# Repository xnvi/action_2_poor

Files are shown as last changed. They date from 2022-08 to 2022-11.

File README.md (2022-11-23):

# 简介
买不起DJI Action 2的我仿造了一台Action 2 Poor  

硬件原理图  
https://oshwhub.com/code504/action_2_poor_v1  

软件源码  
https://gitee.com/dma/action_2_poor  

视频演示  
https://www.bilibili.com/video/BV1ND4y1s7Hr  

# 写在前面
* 想买个便宜运动相机的、零基础的、纯外行之类的人不要看了，直接去买便宜的二手运动相机。
* 想要复刻的一定要考虑清楚，千万不要把它真的当成相机来用，视频中也展示过它的画质，这里我再次强调：它的画质很差！
* 本项目的学习意义大于使用意义，如果你以前没有做过这样的项目并能完整复刻下来，或者能在此基础上做二次开发，那么我相信你一定有巨大收获！

# 目录说明
* doc 为项目文档、图片、部分芯片的数据手册等。
* firmware 为编译好的固件，直接烧录就可以运行，例如uboot、kernel、rootfs等。
* hardware 为硬件相关内容，包括原理图、PCB、外壳模型等。
* software 为软件源码。其中 app 内为各个可独立运行的程序，包括 hello world、camera、功能测试程序等；ext_lib 为第三方库如 lvgl、libmpeg等；hisi_sdk 为海思官方sdk文件；patches 为我修改的u-boot和kernel代码；utils 内为本工程的一些未分类的通用代码。

PCB和原理图仅供参考，后续变更以 https://oshwhub.com/code504/action_2_poor_v1 为准，本工程内的PCB和原理图不再更新。  

# 固件说明
firmware 的目录结构及各个文件说明如下  
```
firmware/
├── camera_img                              # 存放我编译的各类镜像，烧到Flash中就能用
│   ├── rootfs.jffs2                        # 我编译的 rootfs
│   ├── uboot_env.bin                       # u-boot环境变量
│   ├── u-boot-hi3516ev200.bin              # 我编译的 u-boot
│   ├── uImage                              # 我编译的 kernel
│   └── update_pack.tar                     # 升级包示例
├── font                                    # 存放字体文件，大家可以自行修改
│   ├── HarmonyOS_Sans_SC_Regular_L1.ttf    # 中文字体
│   └── Inconsolata-Bold.ttf                # 英文字体
└── hisi_official_img                       # 存放由海思官方代码编译的未做任何修改的镜像，供大家开发测试
    ├── rootfs_hi3516ev200_64k.jffs2        # 由海思官方代码编译的 rootfs
    ├── u-boot-hi3516ev200.bin              # 由海思官方代码编译的 u-boot
    └── uImage_hi3516ev200                  # 由海思官方代码编译的 kernel
```

烧写地址  
| 文件名 | 地址 |
| --- | --- |
| u-boot | 0x00000000 |
| u-boot_env | 0x00080000 |
| kernel | 0x00100000 |
| rootfs | 0x00500000 |

* 理论上由海思官方代码编译的镜像可以直接跑起来，容量为8MB或16MB常见品牌的Flash都是支持的
* 保守起见，我的镜像修改了u-boot和kernel的Flash驱动，至少可以保证使用W25Q128JVSIQ能正常启动
* 烧写方法灵活多样，flash内有uboot的可以直接用uboot命令烧写，没有uboot的flash（如不小心全片擦除、全新flash、flash内数据损坏等）可以用hisi sdk内的烧写工具或拆下flash用烧写器进行烧写。无论哪种方式只要能烧进去就行，具体操作步骤请自行百度或查阅hisi sdk内相关文档，这里不再赘述。

# 快速入门

## 零代码开发
针对不想写代码或不会写代码的人，这种方式风险极高，遇到问题很难定位。  

### 准备工作
1. 有焊接能力
2. 有flash烧写工具
3. 除被动型元件（电容、电阻等）以外的所有器件型号必须完全一致
4. 特别说明：目前提供的固件触摸屏坐标范围是0到128，坐标原点在右下角，如果你的触摸屏不符合这个参数就必须修改源码

### 开发过程
1. 焊接并组装
2. 按【固件说明】章节的内容烧写camera_img目录下对应的固件，烧写完成后最好校验一遍
3. 上电，如果运气好，2秒钟左右你会看到Logo，15秒左右会黑屏，紧接着白屏，22秒左右开机完成
4. 如果没有开机、开机白屏、开机后卡死等，检查芯片是否焊接良好，如果确认焊接无误，大概率是芯片挂了
5. 如需帮助请留下详细的故障描述以及完整的串口打印日志（波特率115200），特别是串口日志，非常重要！

## 二次开发
我默认你具备足够的软硬件开发经验，能独立解决开发中遇到的各种软硬件问题，一些基础性的东西例如设置uboot环境变量、编写CMake脚本、git常用命令、Linux常用命令等我默认你都会。  

### 准备工作
1. 有足够的C语言开发经验，具备一定Linux基础，有焊接能力
2. 准备海思官方SDK，版本为 Hi3516EV200R001C01SPC012 （这东西是保密的，我不想给自己找麻烦，别找我、我没有、不知道，否认三连。【疯狂暗示：用各种搜索引擎搜索“Hi3516EV200R001C01SPC012”、“海思SDK”、“Hi3516EV200 SDK”等关键字，这里的各种搜索引擎包括但不限于百度、Bing、Google、网盘搜索、磁力搜索、各种论坛的内部搜索、某些购物软件的搜索栏、公众号等】）
3. 按照海思SDK中的说明安装交叉编译工具链 arm-himix100-linux
4. 如果你想要自己编译uboot、kernal、rootfs，请按照海思SDK中的相关文档搭建开发环境；如果不想编译上述内容，可以跳过这个步骤，直接用我提供的
5. 拷贝海思官方SDK内的相关文件，本工程用到以下文件：
	hisi_sdk 内用于存放海思官方sdk文件
	请自行拷贝以下文件到 `hisi_sdk\` 目录内
	Hi3516EV200R001C01SPC012.rar -> Hi3516EV200R001C01SPC012\01.software\board\Hi3516EV200_SDK_V1.0.1.2.tgz -> Hi3516EV200_SDK_V1.0.1.2\package\mpp.tgz -> mpp\
	这个目录下的 include, ko, lib 三个目录

### 编译说明
在 `software/CMakeLists.txt` 中设置海思交叉编译工具链路径  
编译命令  
```
cd ./software
mkdir ./build
cd ./build
cmake ../
make
```

### 运行程序
**有嵌入式linux开发经验的可以自行操作，本章节内容仅供参考**  

烧写完成后需设置uboot环境变量，输入以下命令设置环境变量，保存并重启，正常情况都会成功。  

我编译的镜像使用以下环境变量  
```
setenv bootargs 'mem=36M console=ttyAMA0,115200 clk_ignore_unused rw root=/dev/mtdblock2 rootfstype=jffs2 mtdparts=hi_sfc:1M(u-boot.bin),4M(kernel),11M(rootfs.jffs2)'
setenv bootcmd 'startrgb; sf probe 0; sf read 42000000 100000 400000; bootm 42000000'
setenv bootdelay '1'
saveenv
reset
```
为了加快开机速度可以把 bootdelay 改成 1，但不建议改成 0，你清楚这意味着什么吧？  

海思官方镜像使用以下环境变量  
```
setenv bootargs 'mem=32M console=ttyAMA0,115200 clk_ignore_unused rw root=/dev/mtdblock2 rootfstype=jffs2 mtdparts=hi_sfc:1M(u-boot.bin),4M(kernel),11M(rootfs.jffs2)'
setenv bootcmd 'sf probe 0; sf read 42000000 100000 400000; bootm 42000000'
saveenv
reset
```

**以挂载nfs并运行程序为例**  
linux内核启动后输入以下命令启动网卡、设置IP、网关等  
```
ifconfig lo 127.0.0.1
ifconfig eth0 192.168.1.2 netmask 255.255.255.0
route add default gw 192.168.1.1
```

在虚拟机中安装nfs server，设置有线网卡的ip为`192.168.1.3`，在开发板上挂载nfs（土豪可以用NAS之类的，普通人用linux虚拟机）  
```
mount -t nfs -o nolock 192.168.1.3:/home/nfs /tmp/nfs
```

在nfs server的目录内准备上文提到的ko、lib目录，以及要运行的程序，输入以下命令加载ko  
```
cd /tmp/nfs/ko
./load3516ev200 -i -sensor0 imx335
```
load3516ev200 脚本中的内存可以自行修改，但必须和bootargs的mem保持一致  

输入以下命令设置环境变量  
```
export LD_LIBRARY_PATH=$LD_LIBRARY_PATH:/tmp/nfs/lib
```

运行你的程序  

# 硬件开发

## 硬件成本与采购渠道
如果你打算自己手工焊接，并且使用3D打印外壳，成本最低可以控制在300元以内，但如果你打算正反面全贴片并且使用CNC外壳，那么会直接飙升到一千元，总之就看你的钱包能不能承受得住。  
为避免不必要的麻烦，详细内容以及采购渠道请查看 doc 目录中的《成本估算及采购渠道.xlsx》  

## 打样参数
| 名称 | 层数 | 厚度 | 备注 |
| --- | ---- | --- | --- |
| 串口网口转接板 | 2 | 无要求，1.6mm即可 | 无 |
| 屏幕转接板 | 2 | 尽量薄，建议0.8mm | 无 |
| 副板 | 2 | 建议0.8mm | 有能力的最好做阻抗匹配 |
| 主板 | 4 | 建议1.0mm | 有能力的最好做阻抗匹配 |

## 串口与网口转接板
4块PCB中最简单的一块，就是把串口和网口引出来而已，方便调试。串口的作用还用说？网口主要是挂载NFS进行开发调试，不用网口也行，无非就是用SD卡烧写程序测试，但这样做效率太低，而且不能用GDB Server进行调试。  
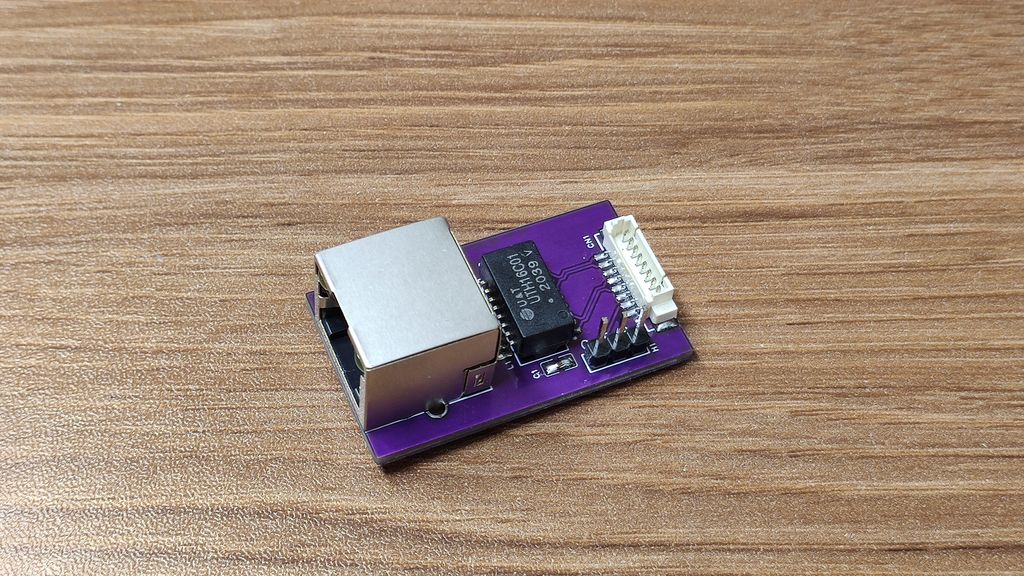
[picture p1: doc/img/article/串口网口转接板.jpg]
  

## 显示屏与触摸屏转接板
显示屏与触摸屏通过一块转接小板与主板连接，这样设计有两个原因：  
1. 主板没有多余的面积放置显示屏与触摸屏的接插件
2. 当后期需要更换线其他型号显示屏或触摸屏时，只需重新画转接小板即可

转接板尽量薄一些，这样可以尽可能多得节省内部空间来放置更大容量的电池。这里转接板的厚度为0.8mm，是嘉立创能免费打样的最小厚度。  

**规格型号**  
触摸屏：1.54寸，主控FT6206，6PIN，IIC接口  
显示屏：1.33寸，主控ST7789，12PIN，SPI接口  

**注意事项**  
1. 市面上有很多儿童手表或智能手表的屏幕总成，理论上买这种屏幕是最好的，但我找了多家店铺屏并没有找到合适的屏幕，主要有以下几个原因：没有合适的尺寸；采用BTB接口的屏幕较多，母座难以手工焊接；最重要的一点，没有引脚定义，更不知道触摸屏和显示屏芯片的型号，大多店家只是代理商，他们只负责销售，不是他们不提供资料，是他们也没有资料。如果大家能找到合适的且有完整资料的手表屏幕总成，欢迎分享。（当我整理文档时网上已经可以买到一款1.69寸240x280的屏幕总成了，很多开源项目也在用这款屏幕，但很可惜长度长了一些，不然我就换用这款屏幕了）
2. 显示屏优先选择1.33寸的（有的可能叫1.3寸），不推荐1.44寸和1.54寸。1.44寸的屏幕尺寸比较合适，但分辨率只有128x128，如果你一定要用这款屏幕，那么所有和显示先关的代码都要改，工作量可不小。1.54寸的屏幕显示区域和触屏区域完美重合，但很可惜显示屏的四个角会超出触摸屏一点点，如果显示屏边框是塑料，可以尝试用刀割一点点，如果显示屏是金属外壳就不太好办了。其次是留给触摸屏四周的边框太窄了，和外壳粘接比较困难，还有就是屏幕排线的位置也不太合适，排线距离边框太近，安装时外壳可能会过渡弯折排线导致屏幕损坏。所以我这里只能选用1.33寸的屏幕，这个显示屏和触摸屏之间有大约1.5mm的白边，不易处理，而且显示面积小，确实有点费眼睛。这两种种屏幕对比如下：
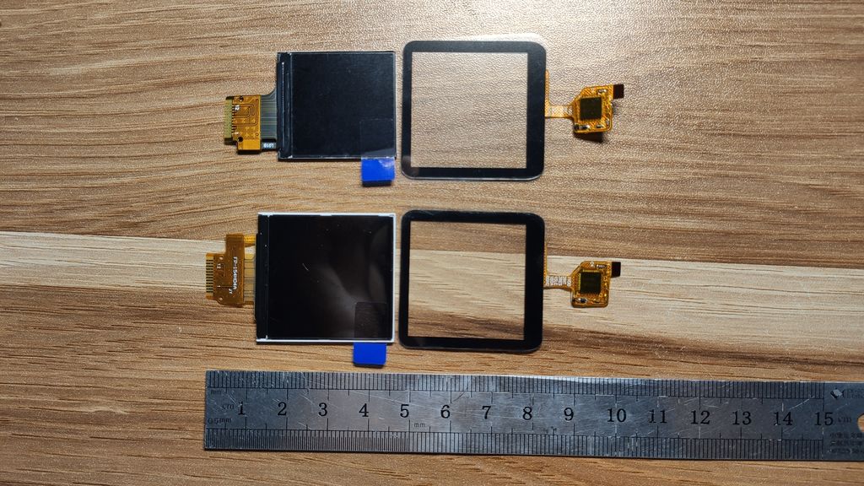
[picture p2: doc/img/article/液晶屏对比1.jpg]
     
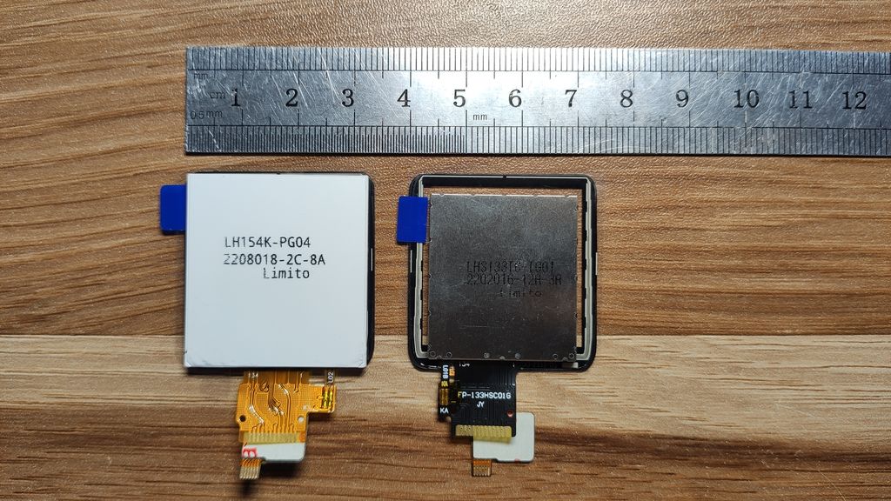
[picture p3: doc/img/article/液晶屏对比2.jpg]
     
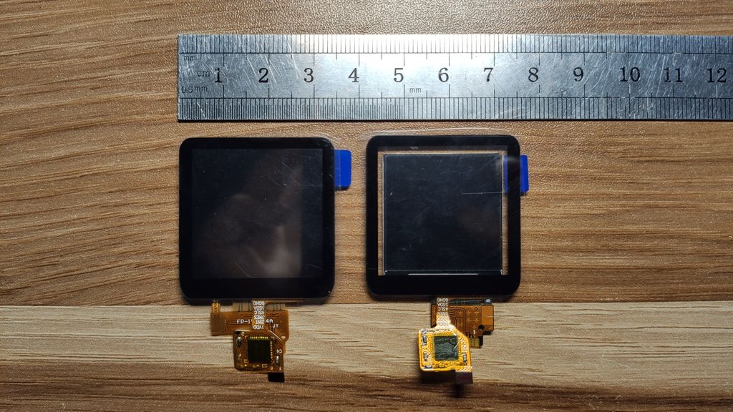
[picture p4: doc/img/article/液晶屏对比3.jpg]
     
3. 如果换了不同尺寸的显示屏，最好在代码中校准一下触摸屏和显示屏的坐标，比如我用的1.33寸显示屏比触摸范围小一圈，触摸的横纵坐标应该都减去一定值，具体内容看源码
4. 最开始我打算用黑色的T7000手机屏幕维修专用胶水来粘接显示屏与触摸屏，正好黑色也可以遮挡白边，计划是将胶水涂在显示屏与触摸屏接触面的拐角处，并用胶水覆盖白边，这样粘接的好处是一旦发现触摸屏或显示屏有损坏等情况，除胶拆卸也比较方便。真正粘接前还专门在钢化玻璃贴膜和亚克力上试了试，发现胶水的流动性不强，我以为没问题，实际粘接时发现胶水会渗入屏幕之间，幸亏拆的快，不然这两块屏幕就有可能报废了。所以我最后用3mm宽的黑色的手机维修泡棉双面胶来粘的屏幕，这三边用黑色泡棉胶带呈L形粘贴屏幕边框和触摸屏。
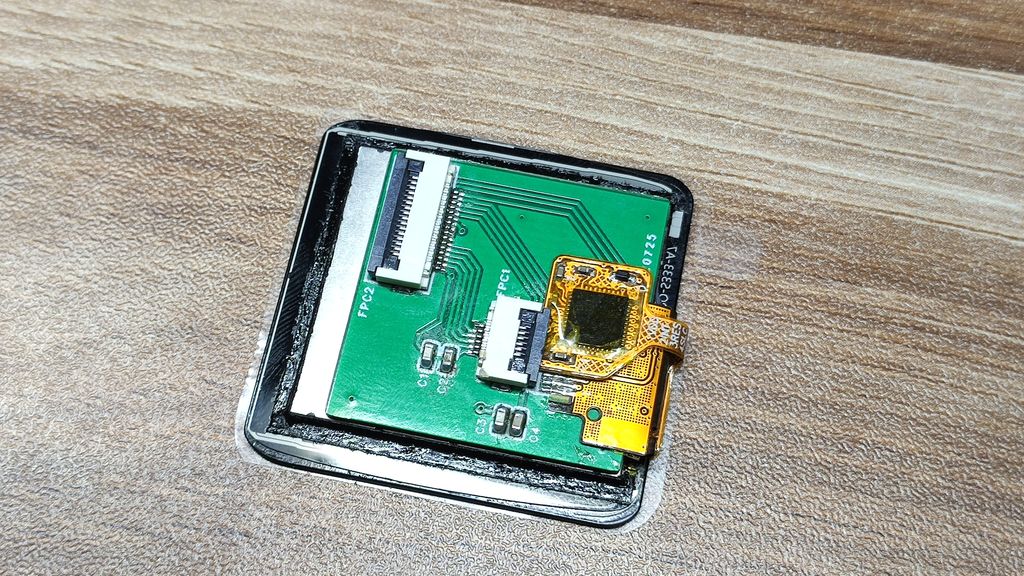
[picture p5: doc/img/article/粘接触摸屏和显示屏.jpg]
     
5. 如果不打算维修，或不考虑以后进行无损拆解等，可以考虑OCA光学胶，这也是理论上最理想的选择，因为现在几乎所有的手机屏幕都是用这种胶粘的，但实际情况是没有专业工具粘接必然有气泡残留，这胶的粘性还挺强，后期维修拆解困难，残留难以清除（看维修手机的视频就知道这胶有多难处理），所以也不推荐。如果你是个修手机的，手头正好有压屏机，那当我没说。我用两张报废的手机膜做测试，粘接后有气泡残留。
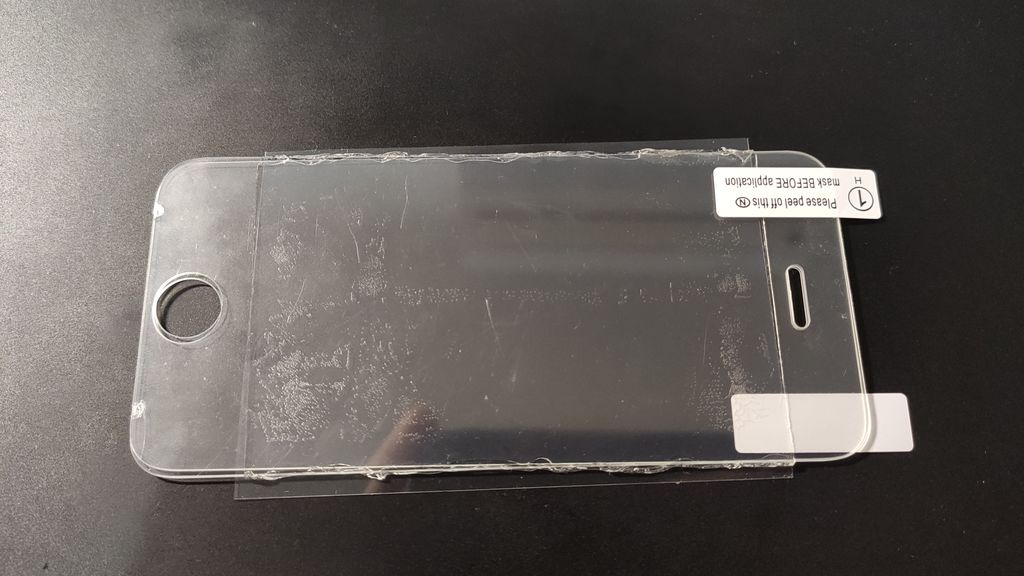
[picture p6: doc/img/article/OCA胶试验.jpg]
     
6. 触摸屏的FPC排线很短，FPC座这里的小突起会压到触摸屏排线，需要把这里剪掉，推荐用指甲刀
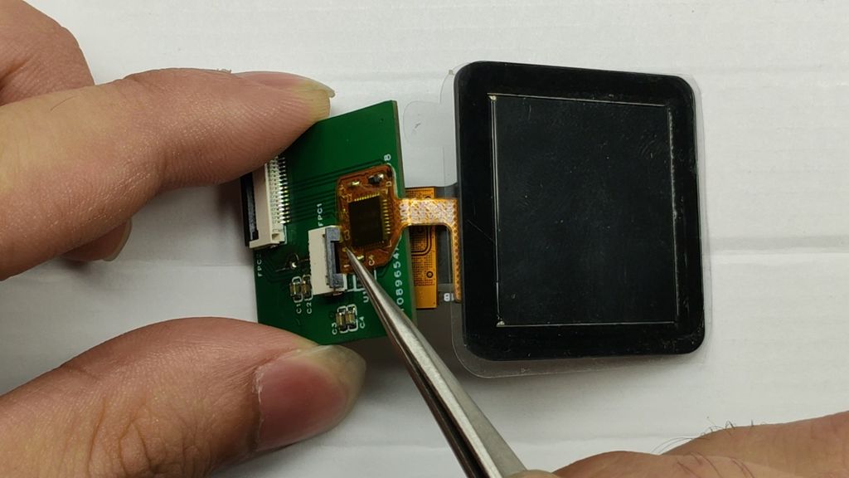
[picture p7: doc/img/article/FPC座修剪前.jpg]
     
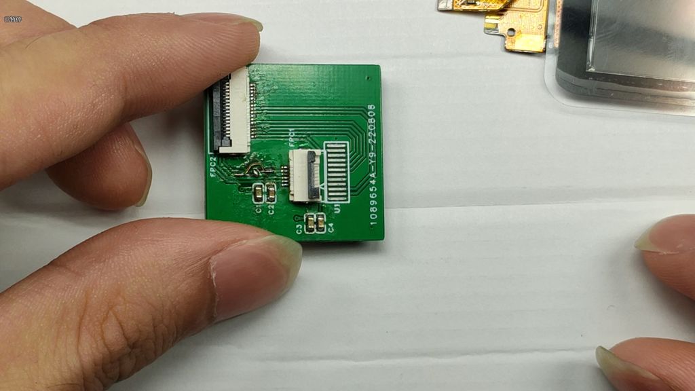
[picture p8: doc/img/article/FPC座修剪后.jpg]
     
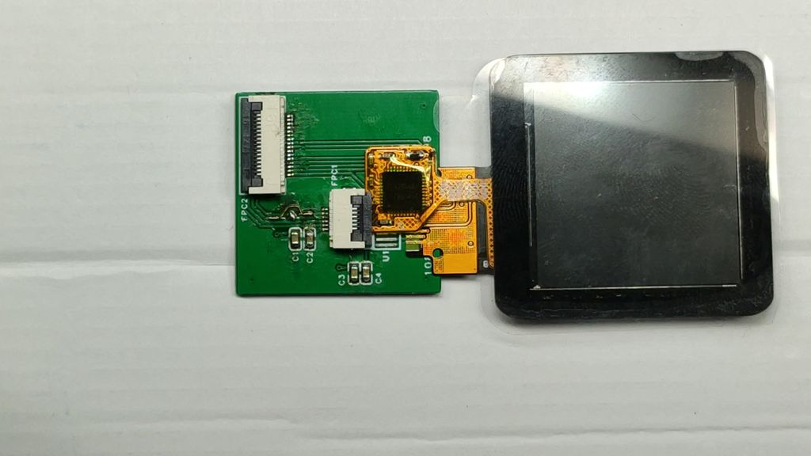
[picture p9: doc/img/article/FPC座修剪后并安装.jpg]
     

## 副板
1. 目前没有做回放功能，也没有提示音之类的，可以不焊接功放芯片。
2. type-c有两对信号线，我的PCB中只连接了一对，不影响使用，何况我也没开发USB功能，如有需要请自行修改。
3. USB信号线没做阻抗匹配，如有需要请自行修改。
4. 充电芯片是TP4057，目前设置的充电电流大约为0.36A，且电源输入端加了分压电阻，芯片几乎不发热。如需调整充电电流请注意散热问题。

## 主板
1. 在主板的Flash旁边预留了5V和GND焊盘，开发期间可以用这个焊盘供电，省去电池。也可以给副板的电池引线接上可调电源。
2. 主板左下角和右下角螺丝孔旁边故意没有铺铜，外壳（尤其是CNC外壳）这里如果有弧度正好可以手动把这里磨成圆的。为什么不在PCB里面就做成圆的？因为懒。
3. 主板上其他设计细节请查看原理图中的注释
4. MIPI、ETH、USB信号线需要做阻抗匹配，但是我没做，能用就行。（其实是我不会）
5. 主控我买的二手拆机摄像头，这种价格便宜但不包好坏，有的板子有明显的暴力拆解痕迹，这种芯片完全看运气。

谁呀这么倒霉？怎么这么多芯片都坏了？哎？你们别看我，这个倒霉蛋绝对不是我！我不知道，我没有狡辩，真的不是我！  
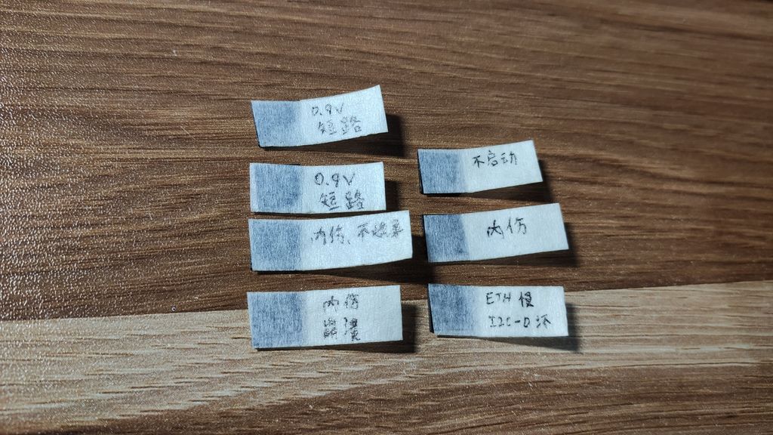
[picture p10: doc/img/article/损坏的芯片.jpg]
  

## FPC排线处理
* FPC排线的长度建议为3CM
* 为了节约PCB面积整个电路设计很紧凑，所有FPC连接器的位置都很靠边，而FPC加强筋又比较长，不方便弯折，所以需要减掉一些加强筋。
* 如果加强筋的金手指比较长，可以直接从加强筋前面减
* 如果加强筋的金手指比较短，需要从后面把加强筋和排线撕开，然后剪短（有的排线质量非常好，加强筋根本撕不开，可以适当加热辅助，如果还撕不开就换个渠道再买一些吧）
* 推荐使用指甲刀剪

剪加强筋之前  
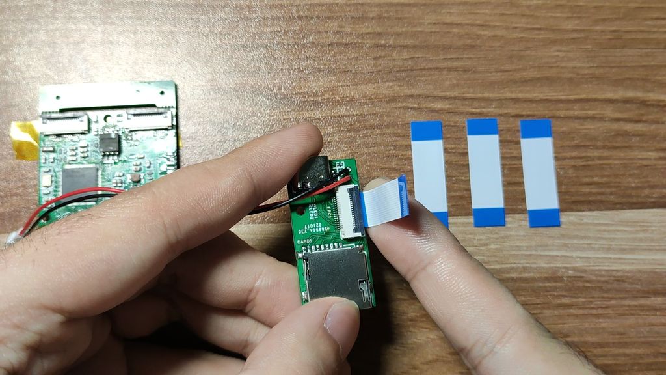
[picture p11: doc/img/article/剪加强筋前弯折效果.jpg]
  
剪加强筋之后  
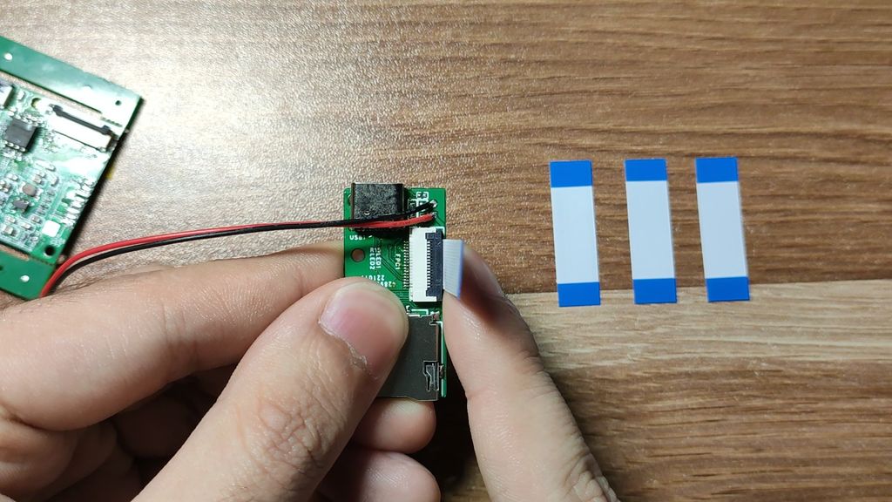
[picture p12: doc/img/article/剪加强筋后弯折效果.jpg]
  
撕加强筋  
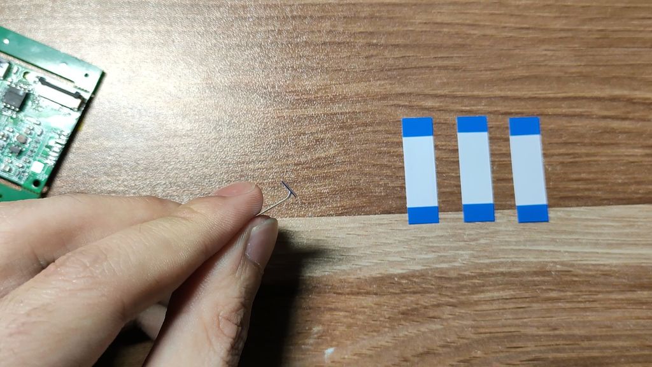
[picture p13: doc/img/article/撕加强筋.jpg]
  

## 摄像头处理
摄像头的排线需要弯折，弯折后效果如下，保证摄像头正好在线框位置上，并使用双面胶粘牢  
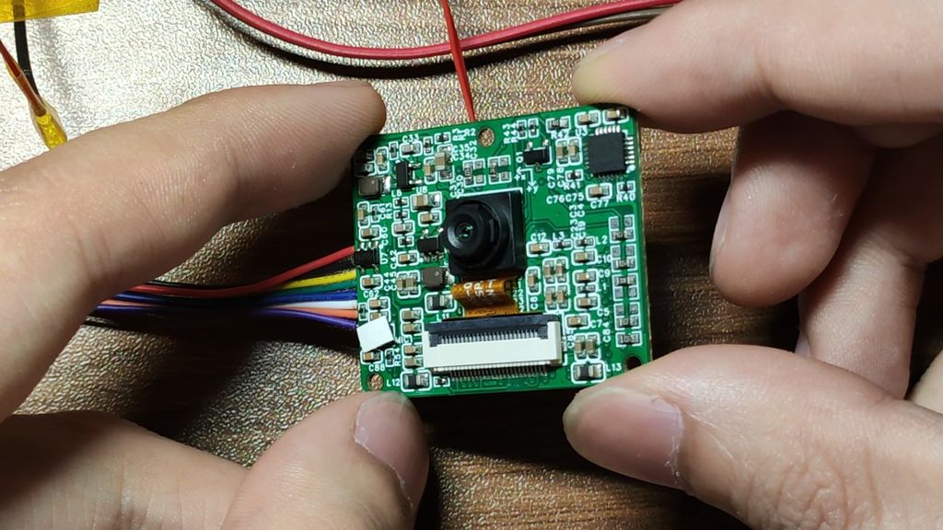
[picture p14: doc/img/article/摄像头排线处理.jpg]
  

## 主控芯片焊接注意事项
1. 一定要检查，有维修专用显微镜之类的最好，如果没有，最起码也要买个10倍的放大镜，引脚非常小，没有放大镜的话你的眼睛受不了。
2. 有钢网可以直接用热风“木仓”一次性焊好，没有钢网先用热风“木仓”把底部焊盘焊好，再用烙铁焊接引脚（焊接老手直接用热风“木仓”搞定，根本不用烙铁补焊）。
3. 焊接引脚没什么技巧，多多练习，熟练了就好，如果你能顺利手工焊接ESP32，那么焊接这个芯片相对来说也没那么困难。

以下是个人总结的手工焊接建议，仅供参加考  
* 这个芯片的主要来源是拆机芯片，焊接前仔细清理引脚（如果能买到全新，忽略此条）
* 手工烙铁焊接不建议用锡膏，因为在芯片的边角处很容易残留未熔化的锡膏，可能埋下隐患，这些未熔化的锡膏用放大镜仔细检查就能发现，但肉眼基本看不见
* 烙铁头个人觉得用小刀头最合适，其次是小一字头，再其次是特尖头，马蹄头不考虑
* 助焊剂优先推荐BGA专用助焊剂，再其次是一些维修专用助焊剂；不推荐松香（残留多，不方便后期检查），千万不要用一些弱酸性或可能具有轻微导电性的助焊剂，这种助焊剂如果洗不干净隐患无穷
* 少加一点点助焊剂，一点点就行，烙铁头带适量焊锡，从左到右慢慢拖焊，经验丰富的老手用适量的助焊剂和焊锡拖焊一遍就能成功
* 焊接完成后一定要用放大镜仔细检查

这是购买的二手电路板没有拆下芯片之前的样子，焊接效果良好、锡球饱满  
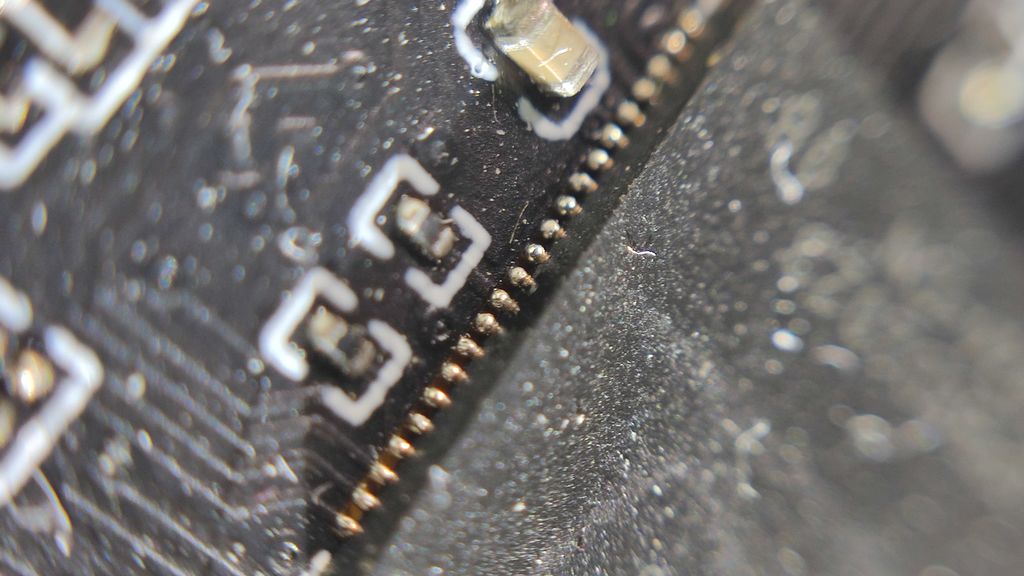
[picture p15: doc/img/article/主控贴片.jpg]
  
正常焊接后的效果如下，可以看到QFN侧面引脚都有锡  
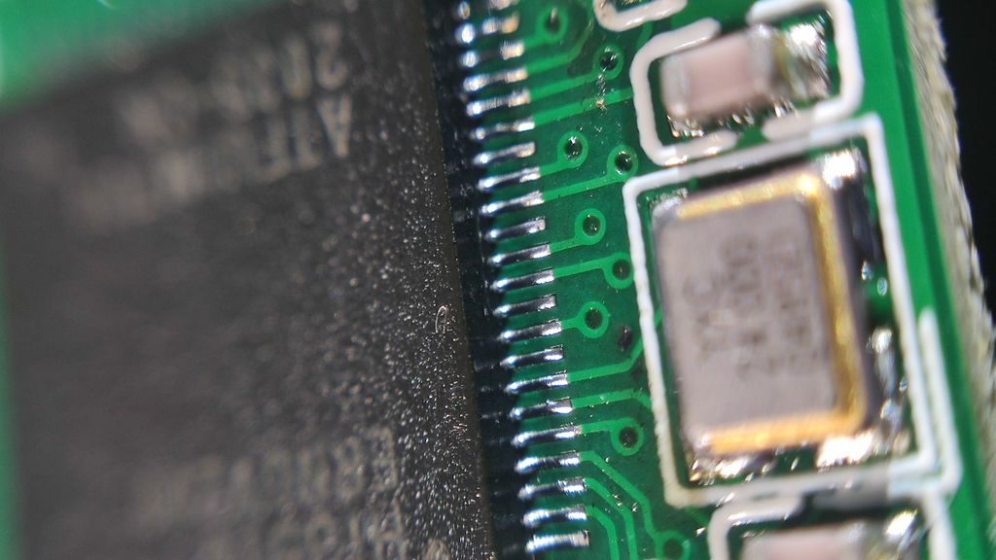
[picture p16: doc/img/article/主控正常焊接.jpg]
  
虚焊的效果如下，QFN侧面引脚没有锡  
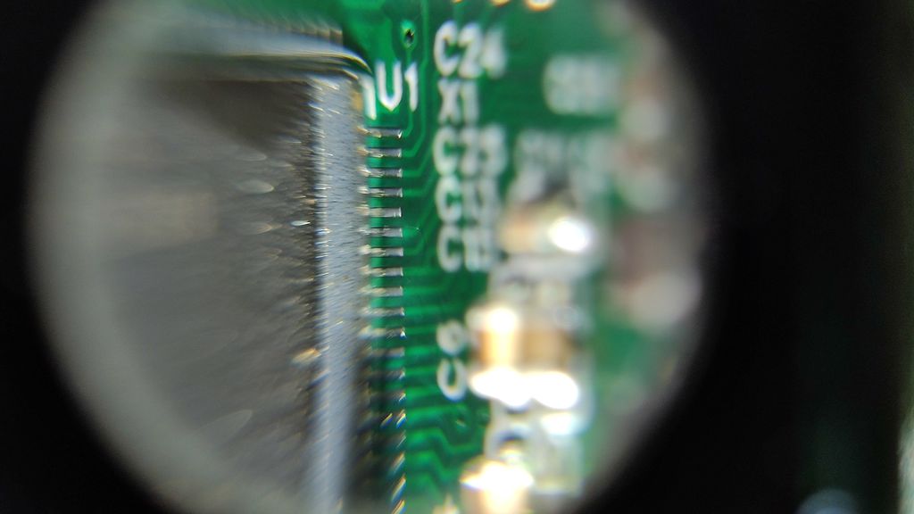
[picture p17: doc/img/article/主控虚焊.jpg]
  

## 其他芯片焊接注意事项
* 当前使用的这颗硅麦需使用热风“木仓”焊接
* 焊接硅麦时特别要小心，任何助焊剂等物质不得进入麦克风的收音孔内（这是麦克风的手册中特别强调的内容）
* 洗板时也要注意，任何洗板水等物质不得进入麦克风的收音孔内（这也是麦克风的手册中特别强调的内容）

# 结构开发

## 3D打印外壳
* 首先排除树脂（如果是自己打印排除PLA），原因是不耐高温，三维猴提供的几种树脂材料的热变形温度差不多在60度左右（PLA的热变形温度也差不多是60度左右），相机工作时发热量巨大，会导致外壳变形。
* 优先选择尼龙，它的热变形温度接近100度左右，价格也不贵。
* 不差钱可以考虑工程塑料，也耐高温，价格比尼龙略贵。
* 至于不锈钢3D打印，价格几乎和CNC差不多，有土豪朋友可以试试，我的钱包伤不起。

## CNC外壳
* 根据工艺不同价格约220到240左右。
* 目前我采用的工艺为：±0.10mm Ra3.2 喷砂-120目 普通阳极氧化-10-15μ-亮光

## 按键
* 按键采用iphone4、5、6的home键，价格在1到3元左右。
* 不要买6s及之后的按键，它有指纹，且价格更贵。

## 电源开关
想打印的就去打印，不想打印的找一小块塑料，自己用刀子刻一个也行（谁小时候没有刀子刻过铅笔呢？）  

## 镜头膜
* 买随便买一个大疆Action2的镜头钢化玻璃膜就行
* 各家店的镜头膜尺寸不同，以我手头为例，就有29mm和28mm两种，强迫症自己去改模型，不是强迫症就凑合用吧
* 很多人不知道的是钢化膜内层其实还有一层膜，记得把它撕掉，然后再用透明双面胶（例如0.1mm到0.3mm厚PET双面透明胶）或胶水（例如UHU胶）什么的把它粘在外壳上

我手头的两种钢化膜尺寸  
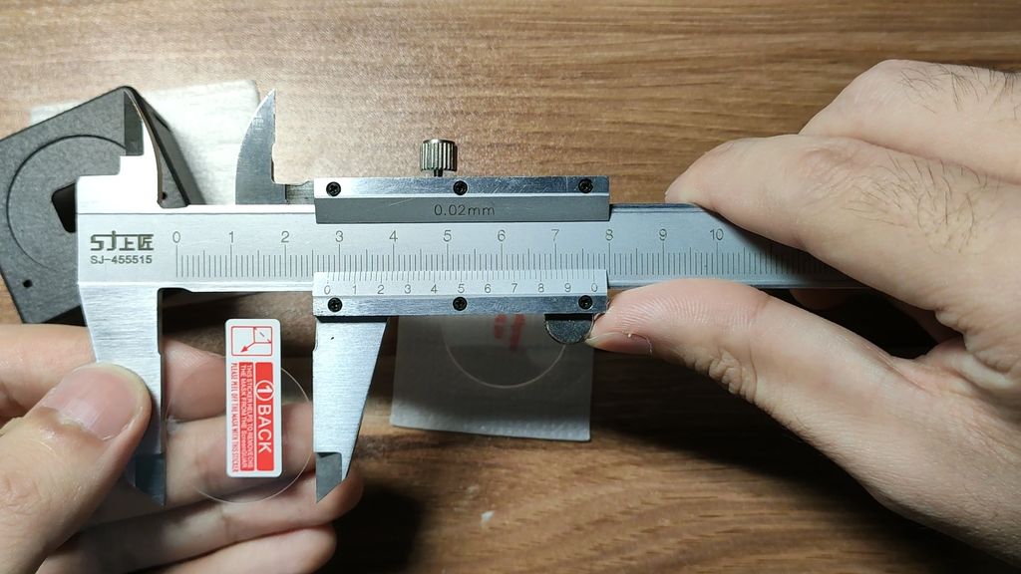
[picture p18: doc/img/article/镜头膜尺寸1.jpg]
  
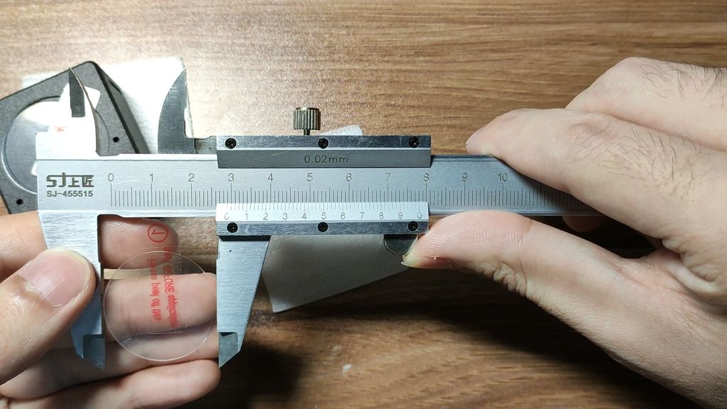
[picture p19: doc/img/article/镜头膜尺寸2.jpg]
  
钢化膜内层的膜用小刀稍微使劲就能划出痕迹  
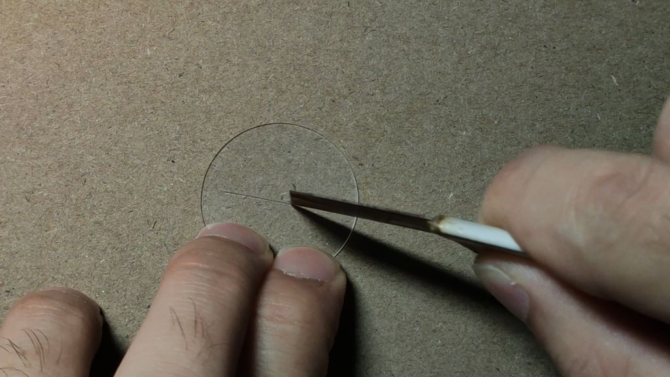
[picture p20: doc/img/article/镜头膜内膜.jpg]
  
再使点劲把膜划烂，撕掉就行，安全第一，注意别伤到手，也别把钢化玻璃弄碎了  
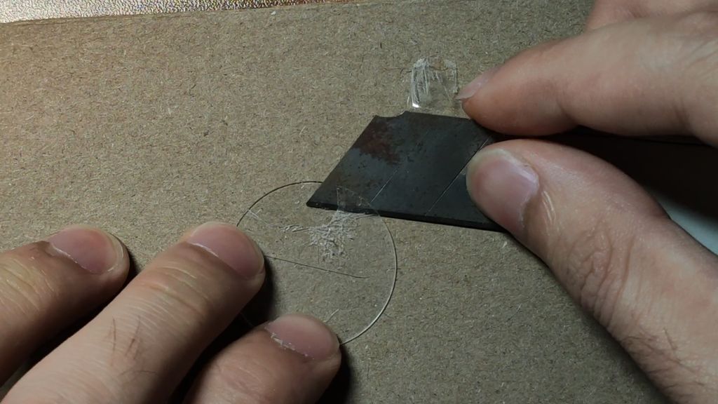
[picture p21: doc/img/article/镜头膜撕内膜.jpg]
  

## 外壳组装说明
先说一个很严重的问题：铝合金外壳会干扰电容屏，从电容屏的原理上讲，这是无法避免的。我尝试了加厚电容屏下胶带厚度，使电容屏尽量远离金属边框，但依然有干扰，所以最后无奈只能使用3D打印的边框，视频中也能看到，成品前面两个外壳用的是铝合金，后面屏幕边框用的是尼龙，外观有点丑。如果有行之有效的改善电容屏干扰的方法，欢迎与大家分享！  

CNC外壳前期准备工作  
* 对于CNC外壳定义装镜头玻璃的为前壳，中间的为侧壳（中壳），装屏幕的为后壳
* 使用透明环氧胶将前壳和侧壳粘在一起，前壳和侧壳要一次性粘接到位
* 粘接时必然会有部分胶水溢出，溢出的胶水需要及时处理，一旦胶水固化就难办了
* 个人经验，环氧胶的初步固化时间约5分钟（具体时长看说明书），涂胶后等个两分钟左右，这时胶水的流动性变差但有没有完全凝固，使用类似牙签之类的有一定硬度且不会划伤外壳的东西尽快把溢出的胶水扣掉
* 等待24小时完全固化后你就得到了一个外壳

CNC外壳相比与3D打印外壳少了一些如螺丝柱之类的结构，这样做的目的是为了降低加工费用，也许我这样设计的CNC外壳不够合理，欢迎提出改进意见。  
其余步骤3D打印外壳的组装步骤和CNC外壳的组装步骤基本一致（定义上一步粘好的CNC外壳为前壳，装屏幕的为后壳）
* 对于CNC外壳，购买若干5mm高的m2螺丝柱，对照PCB的螺丝孔位置，使用环氧胶粘在前壳上，待胶水完全固化后再进行下一步
* 对于CNC外壳，如图所示，找一些小塑料块之类的东西粘在距离前边框3mm处，塑料块不要太高，以免碰到副板上的元件，这里的塑料块可以粘死（这一结构是为了辅助固定副板PCB，可参考3D打印的结构）
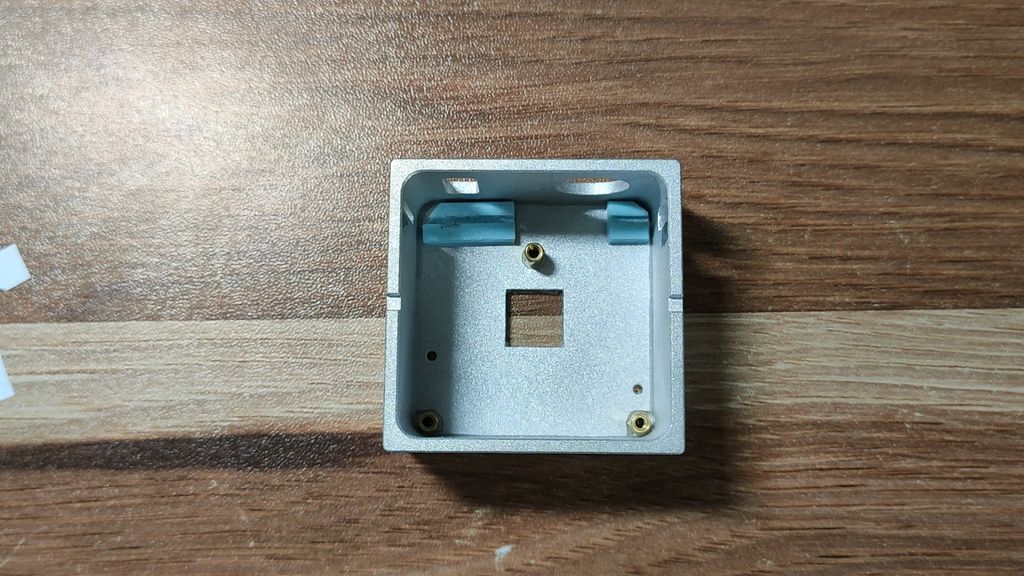
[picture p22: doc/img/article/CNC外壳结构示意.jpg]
  
* 粘钢化膜
* home键和PCB上的按键之间大约有1mm的空隙，可以在home键后粘一小块硬纸板来填补间隙，或者贴片时选用高度为1.6mm的按键
* 使用胶带把home粘在外壳上，别粘死，主要目的是保证home键可以按得动，但又不会按几次以后就歪了
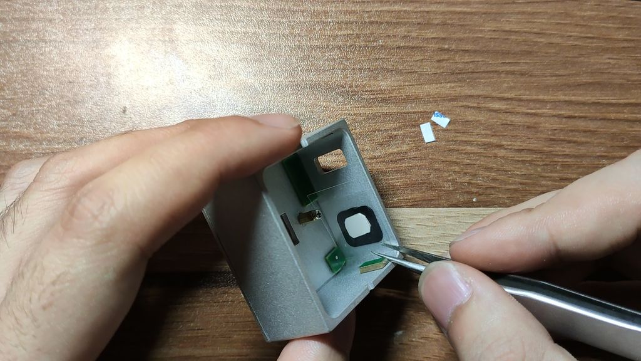
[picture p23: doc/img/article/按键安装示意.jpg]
  
* 需要喇叭的，安装喇叭，3D打印外壳上预留有安装位置，CNC外壳就凭感觉差不多是这个位置就行
* 先插好副板的排线再将副板随开关帽一起装入外壳
* 对于CNC外壳，如图所示，找一些小塑料块之类的东西分别粘在USB插口处和SD卡插口处，塑料块高度约3mm，这里的塑料块不要粘死，除非你以后不打算拆开维修了（这一结构是为了辅助固定副板PCB，3D打印的外壳不需要这个结构，后壳上突出的柱子起相同作用）
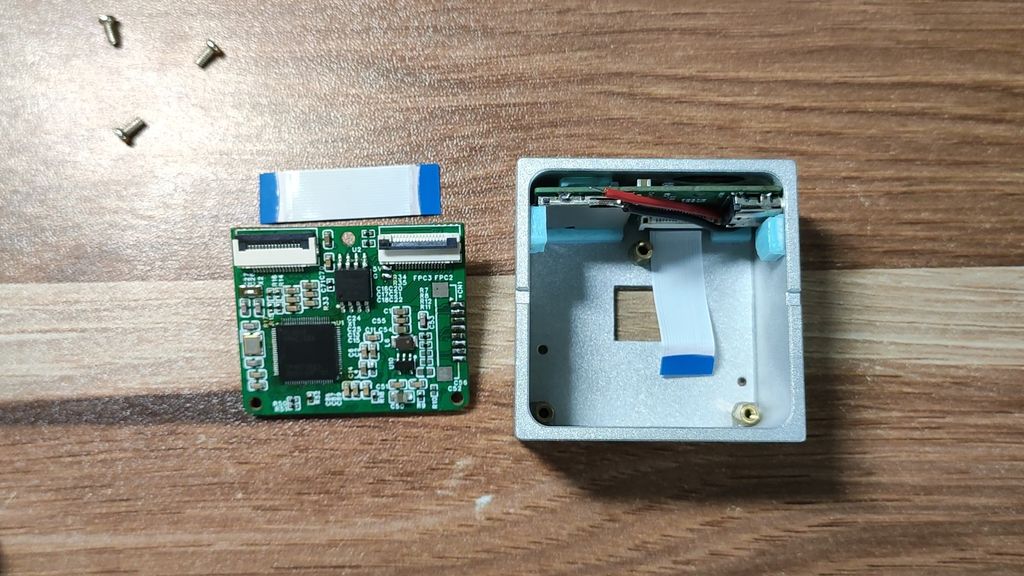
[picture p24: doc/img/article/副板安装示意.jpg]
  
* 先插好屏幕排线和副板排线，再将主板装入外壳并用螺丝固定
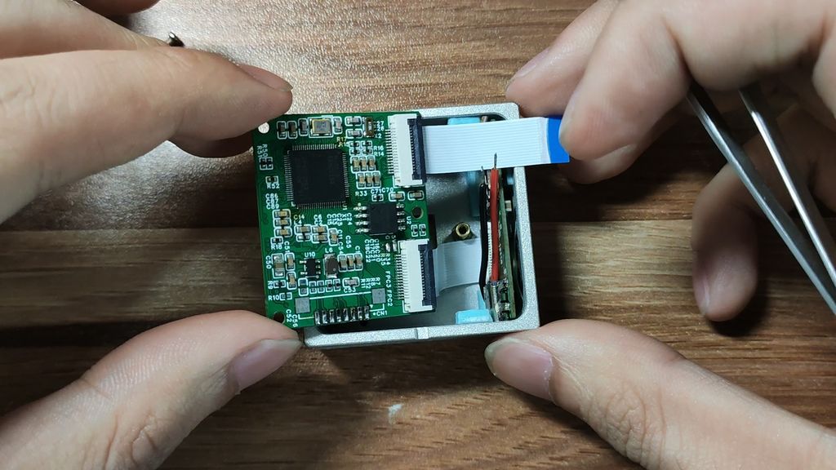
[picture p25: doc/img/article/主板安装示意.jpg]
  
* 对主板上的所有器件用胶带做绝缘，仅露出主控
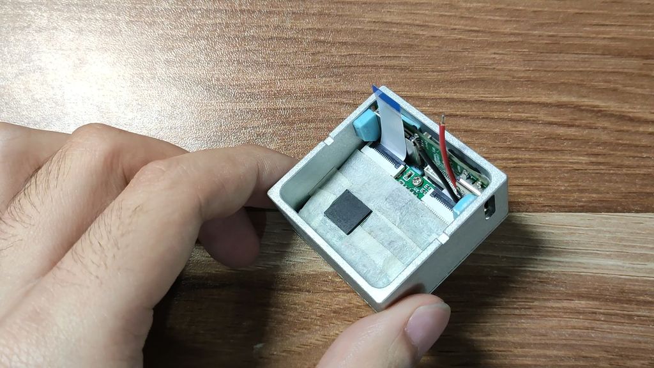
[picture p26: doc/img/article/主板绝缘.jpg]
  
* 给主控粘铜箔胶带辅助散热（手机上的哪种石墨散热贴也行），注意铜箔胶带一定要粘到外壳上，目的是提高散热效率。3D打印外壳的散热效果肯定差，没办法
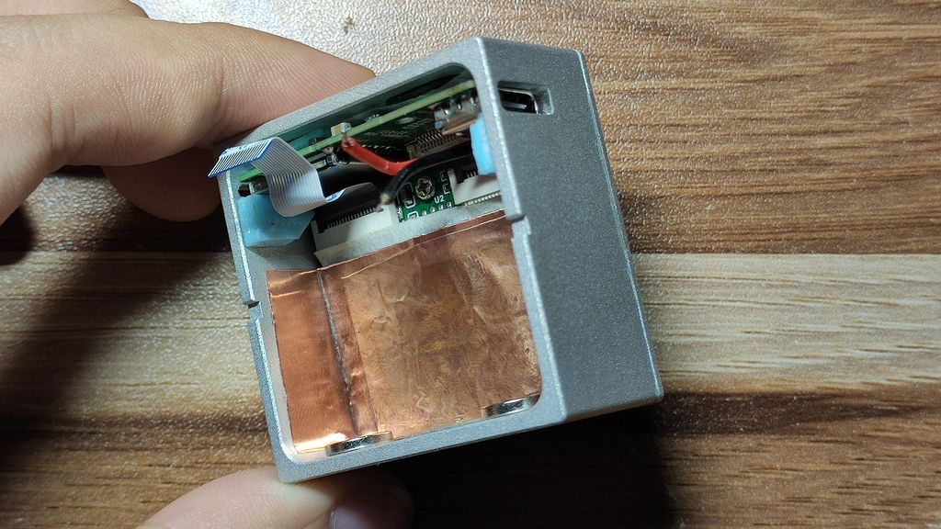
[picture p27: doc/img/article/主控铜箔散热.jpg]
  
* 再次强调，主控的发热量比较大，不辅助散热的话温度会直接飙升到100度以上，手册中建议工作温度不要超过95度
* 使用宽度为3mm左右的双面胶把屏幕粘在后壳上
* 安装电池，连接屏幕排线
* 使用双面胶将后壳和前壳粘在一起，同样不要粘死，除非你以后不打算拆开维修了。注意到样机的左右边框有两个缺口吗？就是为了方便我自己从这里撬开屏幕进行后期维修预留的
* 大功告成

# 软件开发
海思的SDK可以说是我目前接触到的文档资料最好的SDK，没有之一。他的文档规范、覆盖面广，开发过程中90%的问题都能通过文档解决。其他芯片例如全志、君正等仍然存在一定差距。  

软件开发第一步搭建开发环境，按照上文说明下载指定版本SDK，并根据SDK内的文档说明安装交叉编译器、释放源码等。  

软件开发没什么好说的，看代码、看注释吧，本章节只挑一些比较重要的内容进行说明。  

## 字体
中文字体选择了一款非常著名的开源字体 HarmonyOS_Sans_SC_Regular，英文字体则选择了程序员中较受欢迎的 Inconsolata-Regular。  

目前我适配了 stb_truetype 作为 LVGL 的字体引擎。我前期开发用的 LVGL v8.3，这个版本官方还没适配 stb_truetype。但后来（大概是2022年9月） LVGL 的 master 分支上官方已经适配好了，叫做 Tiny TTF font engine。我在本项目中就用自己适配的字体引擎，如果没有特殊需求不会切换到 Tiny TTF font engine。  

### 字体裁剪
HarmonyOS_Sans 的具体字符数我不清楚，但有一定可以肯定，它涵盖的字符非常多。对于嵌入式设备来说，使用将近8MB的空间来存储一款字体是一件非常奢侈的事情。查阅相关资料可知中文一级汉字有3755个，足以覆盖日常使用中99%的场景，因此我对它进行了裁剪，只保留一级汉字以及GB2312中前三区的符号，裁剪后的体积只有900KB左右，经过jffs文件系统压缩后实际占用的体积会更小。  

裁剪工具用的是 https://github.com/DeronW/minify-font  
它对应的客户端是 https://ecomfe.github.io/fontmin/#feature  
具体使用方法请自行查阅工具内的文档。  

注：我将裁剪后的字体命名为`HarmonyOS_Sans_SC_Regular_L1.ttf`，其中L1代表一级汉字  

## 如何制作升级包
可以参考 `firmware\camera_img\update_pack.tar` 来制作，这里说几个关键点  
1. 升级的原理就是先删除`/home/app/`，再把升级包内的东西解压到`/home/app/`中，具体细节请查看源码
2. 看清楚升级包的格式`update_pack.tar`，看清除了，是`tar`，也就是只打包不压缩，tar命令的使用请自学
3. 升级包内不包含`app/`这个目录，别套娃了
4. 系统启动后会执行`/etc/init.d/S99user_app`这个脚本，这个脚本只做了一件事就是执行`/home/app/run.sh`，因此如果想要开机启动其他你自己编写的程序修改`/home/app/run.sh`就行
5. 不想使用我的这种升级逻辑的请自行修改相关代码，反正开源了，想咋改都行

## 如何打包rootfs
基于官方的`"Hi3516EV200_SDK_V1.0.1.2\package\rootfs_uclibc.tgz`修改而来，添加了以下内容  
```
/
├── etc
│   └── init.d
│       └── S99user_app                             # 这是我自己添加的开机启动脚本
└── home
    ├── app                                         # 自己编译的程序和相关文件都放这里
    │   ├── camera
    │   ├── font
    │   │   ├── HarmonyOS_Sans_SC_Regular_L1.ttf
    │   │   └── Inconsolata-Bold.ttf
    │   ├── lib
    │   │   ├── libsns_ov5640.so
    │   │   └── ssp_st7789_drv.ko
    │   └── run.sh
    ├── ko                                          # 直接复制海思官方SDK内的对应文件夹
    │   ├── *.ko                                    # 存放海思官方SDK内的ko文件
    │   └── load3516ev200                           # 这个脚本我基于官方修改了MMZ
    └── lib                                         # 直接复制海思官方SDK内的对应文件夹
        └── *.so
```
制作方法  
1. 按官方文档安装必要的工具，例如`mkfs.jffs2`
2. 可以自己从头编译busybox，没有特殊需求直接使用官方的`rootfs_uclibc.tgz`更省事，解压到任意目录例如`./my_rootfs/`
3. 记得 `chmod -R 777 ./my_rootfs/` 否则某些程序无法正常运行，甚至不能自动登录，不能串口输入
4. 添加或修改自己所需要的文件
5. 使用如下命令制作rootfs `mkfs.jffs2 -d ./my_rootfs/ -l -e 0x10000 -o ./my_rtfs.jffs2`

## 另一种升级方式
海思官方还提供了一种方式：SD卡放入相关升级文件，按住UPDATE键开机，系统会自动升级。  
我保留了这种升级方式，录像键就是UPDATE键。详细使用方法请参考SDK内的文档，这里不再赘述。  

## 屏幕刷新率
详细内容可以看《SPI优化》这个文档。  
目前为了降低CPU使用率，故意将LVGL的调用频率和实时预览画面的刷新率降低一些，以保留更多的CPU资源供录像线程使用。毕竟录像功能是最重要的，总不能为了GUI显示流畅而牺牲录像的完整性吧？  

## 图像传感器相关
你问我为什么不使用例如imx307、imx335、sc4236之类的图像传感器？我也想用啊，这些传感器官方SDK里面就把驱动写好了，连ISP都调好了，画质绝对刚刚的！但是网上搜了一番，只能找到IPC通用的镜头模块，别的不说，镜头光学组件的长度就已经超过机身厚度了，我也很无奈啊！所以只能找这种小型镜头，所有能找到的这些镜头里面只有OV5640是支持MIPI输出的，而且也只有OV5640是资料最全的，虽然还有一些神秘寄存器根本找不到说明，但这已经是最好的选择了。还有很重要一点OV5640采用YUV输出模式时可以使用内置的ISP，网上也能找到一些OV5640的ISP配置，我个人没有能力开发海思的ISP。  

首先在这里感谢CSDN一位网友的文章[《Hi3518EV300 OV5640 mipi YUV 调试记录》](https://blog.csdn.net/weixin_43024085/article/details/109478393)  
对我来说这篇文章最重要的是排除了我一个疑惑：Hi3516EV200支持MIPI YUV输入吗？答案是官方SDK里说不支持，但是这位朋友硬是调通了！  
Hi3518EV300 和 Hi3516EV200可以认为主要功能基本一致，有了这篇文章的启发，我也有信心在 Hi3516EV200 上调通 OV5640 MIPI YUV！  

这里直说最重要的修改点，其他参数完全照搬上面这篇文章，至于为什么这样的参数能用，我也不知道，官方说了不支持MIPI YUV输入，这样的配置参数完全是蒙出来的。  

VI模块的相关配置  
```
combo_dev_attr_t MIPI_2lane_CHN0_SENSOR_OV5640_8BIT_NOWDR_ATTR =
{
    .devno = 0,
    .input_mode = INPUT_MODE_MIPI,
    .data_rate = MIPI_DATA_RATE_X1,
    // 手册中说明3516EV200不支持MIPI输入YUV
    // 自己摸索出来的，这里配置的宽度必须是实际宽度的2倍，否则图像缺失
    .img_rect = {0, 0, 3840, 1080},

    {
        .mipi_attr =
        {
   			DATA_TYPE_YUV422_8BIT,
            HI_MIPI_WDR_MODE_NONE,
            {0, 2, -1, -1}
        }
    }
};
```

海思媒体模块初始化完成以后需要修改的寄存器  
```
// HIMPP_VENC_H265_H264 内会改变一些寄存器，OV5640初始化只能放它后面
// VICAP 寄存器，自己摸索出来的配置，手册中说明3516EV200不支持MIPI输入YUV，瞎调给调通了
himm(0x11001010, 0xFF000000);
himm(0x11001014, 0xFF000000);
himm(0x11001040, 0x80000004);
```

## 内存相关
海思将物理内存分为了内核内存和媒体内存，目前设置的是内核36MB、媒体28MB，如需修改一定要详细阅读SDK内相关文档，这里涉及到的东西非常多。  

## 关于u-boot和kernel修改的代码
u-boot 主要修改了两点  
* 增加开机 Logo
* 修改 W25Q128JVSIQ 这颗 Flash 的工作模式，将4线模式改为1线模式，并将时钟频率降低

kernel 主要修改一点  
* 修改 W25Q128JVSIQ 这颗 Flash 的工作模式，将4线模式改为1线模式，并将时钟频率降低

这里解释一下为什么要修改 u-boot 和 kernel 的 Flash 驱动：目前推测是我画的PCB有问题，小概率情况下，不用改驱动系统就能正常启动，大概率不能正常启动，怀疑是SPI时钟太高、有干扰之类的。所以为了确保系统正常启动修改了工作模式和时钟频率。  

## 其他内容
doc 目录下还有几篇文章，想要深入学习的小伙伴可以看看，这些篇文章我也发布在了其他平台。  
[使用NEON指令加速RGB888和RGB565的相互转换](doc\使用NEON指令加速RGB888和RGB565的相互转换.md)  
[SPI优化](doc\SPI优化.md)  

# Q&A
## 能不能做的像 Action 2 一样长按开机、长按关机？
可以，方案都设计好了，但我没做（别问，问就是懒）。这里给出我的设计方案，有兴趣的话可以自己尝试，有更好的方案也欢迎讨论。  
电源控制芯片用STC8G1K08A，DFN封装，一个IO用来控制MOS管，做为电源主控引脚，一个IO接按键，这个IO必须支持外部中断，一个IO接到Hi3516。  
STC芯片内编程，主要功能为：  
1. 按键外部中断唤醒STC，不足5秒进入掉电模式，超过5秒控制MOS管导通使Hi3516开机
2. 短按信号，例如单击、双击、2秒以内的长按原样传输给Hi3516，用来做拍照、拍摄等功能的控制
3. 开机状态下长按5秒，控制MOS管截止，STC进入掉电模式
4. 关机的逻辑可以优化一下，带来更好的使用体验。开机状态下长按5秒，将这个长按的信号也传输给Hi3516，Hi3516收到长达5秒的信号说明这是要关机，在屏幕上显示关机字样或关机动画，STC延时几秒后控制MOS管截止并进入掉电模式

## 能不能用 Hi3518EV300 替换？
可以，改硬件什么的就不说了，这里主要说明换芯片的优缺点。  
对比：3518相比于3516去掉了eth功能和对应引脚改为电源管理相关功能和对应引脚，其余功能基本一致  
优点：3518自带电源管理，不用外接其他芯片就能很方便地实现长按开关机功能，因为款芯片的定位就是消费级电子产品，而不是3516的消费级网络摄像机  
缺点：没有eth，开发会有比较麻烦，比如你的程序不能通过网络挂载，这也就意味着你每次运行都要将程序拷到SD卡里，如果要用网络（比如使用gdbserver调试这种情况），那么你必须开发usb网卡驱动  

## 能不能做视频回放？
当然能做，你看硬件上我都专门为回放功能预留了功放芯片和喇叭，为什么我没做呢？最重要的是开发工作量比较大，挺费头发的，其次这么小个屏幕看回放不难受吗，所以我就砍掉了这个功能？如果你有兴趣的话，可以按照以下方案自己开发。  
首先 Hi3516EV200 没有硬件解码器，回放只能使用软件解码器，其次芯片的性能也有限，据我查到的资料，在某款架构和主频相似的芯片上，使用ffmpeg最高只能实现h264 640x360 12fps的解码。  
结合屏幕刷新率的情况考虑，我设计的解码方案是再开启一路h264的编码器，编码出240x180 15fps的视频，将这个视频保存下来用做回放。这其中还有很多开发工作要做，比如调裁剪ffmpeg并交叉编译、开发GUI等，工作量还不小。  

## 屏幕亮度能不能控制？
可以，屏幕背光引脚接在了PWM上，不过目前只有开关背光的功能，如有需要请自行开发。  

## 如果我想开发wifi模块应该怎么做？
海思SDK内有一篇文档专门讲wifi的使用，芯片型号、编译方法写得很清楚。  

## 安装完SDK发现没有GDB，应该怎么办？
SDK确实没有提供gdb，需要自己编译，具体方法请参考`arm-himix100-linux.tgz\gdb_readme_cn.txt`  

## 为什么配置开发环境遇到了XXX的问题？
你真的按照海思SDK内的文档操作了吗？  
文档中要求你下载的东西都下载了吗？  
什么？你用的是CentOS？为什么不按照文档的要求用Ubuntu？  
脚本不能执行？脚本里写的是`#!/bin/bash`还是`#!/bin/dash`？  
脚本又不能执行？换行符用的是`\n`还是`\r\n`？  
差不多得了，别太过分，你搁这儿十万个为什么呢？自己找答案去！  

## 能不能用旧手机上拆下来的摄像头？
别闹，你是认真的吗？  

## 我想要XXX功能，能不能帮忙开发？
别闹，自己动手丰衣足食！  

## 能不能提供SDK的下载地址？
别闹，谁知道你是不是海思派来的卧底？  

# 关于留言提问
1. 留言第一句问“在吗”，绝对不回复
基本社交礼仪懂不懂？最简单的：表明身份（我是一名程序员；我是一名业余电子爱好者没有编程经验），表明目的（我想要复刻、我买不到元件、我遇到了问题、我发现你的代码有bug），详细说明（我买不到XXX，商品已经下架了；我遇到了问题，串口打印如下XXX；你的bug是XXX，复现的方法是XXX）
1. 提问描述不清的绝对不回复
举两个例子，你猜我会回复哪一种？1.不开机，帮忙看一下。2.不开机，卡在开机Logo，硬件检查过没问题，程序按照说明的方式烧录了，启动后卡在uboot了，uboot代码没有任何修改，尝试换过主控芯片、修改启动电阻、烧录原版镜像等方法都无效，flash型号为XXXX，uboot启动日志如下XXX
3. 能在文档中找到答案的问题大概率不回复
找不到是哪篇文档的我可以指引你去看，文档看不懂可以讨论，文档一个字都不看的你想干啥？
4. 关于技术讨论的尽力回复

# 存在的问题

## 关于月份日期的问题
设置时间日期是一个使用频率很低，但是开发却较麻烦的功能，月份天数不对的问题使用过程中注意就行，暂不修复。  

## 录像开始的前几帧数据异常
确实存在这个问题，应该是第一个I帧前面丢失了PPS数据，会导致短暂的花屏，以后我也许会修吧。  

## 程序退出时偶现段错误
调试过程中正常退出camera程序时有很小概率导致段错误，暂时没有抓到coredump，正常使用都是直接关机，目前而言这个问题暂不影响使用。  

## I2C时钟问题
目前I2C时钟为100KHz，MPU6050的数据量又稍微有点多，会导致I2C占用比较多的内核态CPU（大约20%），我原本想改到400KHz来提升通信效率，但按照海思文档修改后I2C直接没信号输出了，也不知道是哪里出了问题。

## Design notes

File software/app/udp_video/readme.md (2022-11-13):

# 基本功能
udp推流验证视频系统能否正常工作

# 准备工作
电脑需准备ffplay用于播放h264裸流
ffplay如果在 ffmpeg.org 上面有可执行程序的就直接下载，没有的话就下载源码自己编译
有路由器的可以通过网线连接路由器
没有路由器的直连电脑网口

# 使用方法
设备端和PC端设置IP地址

例如
设备端设置如下
```
ifconfig lo 127.0.0.1
ifconfig eth0 192.168.1.99 netmask 255.255.255.0
route add default gw 192.168.1.1
```
PC端设置如下
```
ifconfig eth0 192.168.1.106 netmask 255.255.255.0
```

设备端运行程序

PC端输入以下命令观看h264视频
`./ffplay "udp://192.168.1.106:34543" -fflags nobuffer -flags low_delay -f h264 -threads 1 -thread_type frame -infbuf -an -sync video -fast -x 640 -y 360 -analyzeduration 100000 -framerate 30 -vf setpts=0.9*PTS`

PC端输入以下命令播放aac音频
`./ffplay "udp://192.168.1.106:34543" -fflags nobuffer -flags low_delay -f aac -threads 1 -thread_type frame -infbuf -vn -sync audio -fast -analyzeduration 100000`

简单解释几个参数
1. udp://192.168.1.106:34543 这个不用解释了吧
2. -x、-y是图像大小，如果电脑屏幕分辨率小于图像分辨率，你的鼠标会点不到关闭按钮，对于0基础的人来说就傻眼了
3. -analyzeduration 100000 码流探测的时间，单位微秒，可以设置在1秒以内，加快出图时间
4. -framerate 30 不用解释吧？填写实际帧率
5. -vf setpts=0.9*PTS 设置回放速率为真实速率的 10/9 倍，也就是略高于真实速率，一定程度上可以避免因为误差等原因导致延迟越来越大的问题，具体效果是不是有用也不好说，有时候不加这个参数也没问题

更多命令参数自行查阅ffplay文档

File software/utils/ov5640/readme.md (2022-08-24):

这是根据海思《Sensor 调试指南》编写的ov5640驱动。  
主要驱动代码逻辑都在 ov5640_sensor_ctl.c 文件内。  
ov5640_cmos_ex.h 和 ov5640_cmos.c 由海思的示例代码中复制而来，仅做简单修改，确保能顺利初始化海思 ISP 模块，无实际意义。

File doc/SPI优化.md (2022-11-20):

本项目中使用的液晶屏主控为 st7789，分辨率 240x240，图像格式 RGB565。

查阅海思相关手册可知，Hi3516EV200 的 SPI 最高速率为 50MHz，理论上每秒钟可以发送 50M/8=6.25MB 数据。假设我需要在屏幕上以30fps的速率全屏实时显示摄像头的预览画面，每秒的数据量为 `240*240*2*30=3456000B=3375KB=3.296MB` ，假设 SPI 工作在阻塞模式，则 cpu 使用率为 `3.296/6.25*100%=52.7%`，看起来还不错。如果我想进一步降低cpu使用率还可以降低预览图分辨率，降低帧率，比如我可以按 240*180 20fps 的规格显示缩略图，那么cpu使用率就可以降到 `240*180*2*20/1024/1024/6.25=26.4%`。

上面这些都是我在写代码前的理论分析，真实效果当然需要写程序简单测试一下。测试代码内容大致如下：使用原生linux提供的 SPI 接口，即`/dev/spidevX.X`，主程序中一个死循环没有sleep，使用不同的颜色不停地刷全屏，看一秒钟能达到多少次，也就是刷新率能达到多少帧。

实际测试结果，每秒大约5次！肉眼可见的慢！能很明显看到刷屏的时候是从上到下覆盖过来的！

这么慢的速率就算以240*180的分辨率来刷新预览画面也只能达到7、8帧的水平，何况cpu使用率是100%，其他业务也没办法正常运行，所以spi的速率必须优化。

第一步当然是用逻辑分析仪或示波器抓实际波形，观察是时钟信号没有达到50MHz，还是有其他地方浪费时间。对于逻辑分析仪而言，要考虑采样率是否足够，例如逻辑分析仪的采样率是100MHz，理论上可以采集50MHz的信号，实际采集50MHz的信号很可能采集不准；示波器也一样，示波器需要考虑的是带宽，一般入门级示波器都有100MHz带宽，问题不大。对了，别拿DIY的示波器来捣乱。

这张图就是我通过示波器抓到的海思 SPI 时钟线上的波形，问题非常明显，发送的两个字节之间间隔了 1.656us！开发过任意单片机的spi并实际抓过波形的朋友应该都知道，spi的时钟几乎是连续，正常情况下绝对不可能间隔这么长。


再检查一下spi的时钟有没有达到理论的50MHz，8个clk共计160ns，没问题，达到了理论速率。


题外话：为什么50MHz的方波在示波器上显示为正弦波？因为我这款示波器的带宽只有100MHz，50MHZ方波信号本身没有超过示波器带宽的上限，但是它的2n+1次谐波分量远远高于示波器带宽。所以想要勉强看到50MHz方波的波形，那么示波器至少要能采集到3次谐波信号，也就是150MHz的信号，这就需要一个200MHz带宽的示波器（我买不起！）

简单计算一下，发送一个字节需要 0.16+1.656=1.816us，也就是1秒钟可以发送 1s/1.816us=549450B=536.6KB 的数据，这个数据量甚至不足理论值的十分之一，换算下来确实1秒钟也只能刷5屏。所以接下来的目标就是找出到底是什么原因让发送的两个字节之间占用了足足1.6us。

首先我的发送代码中没有加任何延时函数，所以这1.6us的延时只能来自于linux内核spi驱动。

查看linux内核spi相关源码（提前安装好完整的海思开发环境，并下载对应版本linux内核源码，打海思linux源码patch）
`linux-4.9.y\drivers\spi\spi-pl022.c`
由源码可知海思的spi使用的是 ARM PrimeCell SSP (PL022) 控制器，这些驱动代码应该非常成熟了，不会存在这么明显的问题，大概看了看源码也没发现啥耗时的地方，之后专门以 ssp-pl022 和 delay 作为关键字google一番也没有发现类似的问题。思索了一下，我决定放弃修改内核驱动，首先内核代码很成熟，基本轮不到我这种小角色去debug，其次每次修改都要重新编译并烧录内核，太麻烦。所以我决定自己重写一个spi内核模块ko驱动。

非常幸运，在海思SDK的 `drv.tgz\drv\extdrv\ssp-st7789` 中正好有源码，连芯片型号都一样，基于这个代码做一些简单修改就能用。

经过我的一番修改，实际测试下来发现这个ko模块的性能比linux内核spi的性能有一点点提升，延时从1.656us降低到了1.6us以内，基本等于没有优化，这里就不放截图了。

这个代码就比较简单，读起来也不费劲，大概看了一下还是能找到一点优化的地方，注意看`spi_write_XXbyte`这几个函数，这几个函数内都有这样的代码
```
spi_enable();
ssp_writew(SSP_DR,spi_data);
ret = hi_spi_check_timeout();
if(ret != 0)
{
    printk("spi_send timeout\n");
}
spi_disable();
```
在前面的代码中设置过CS片选信号由spi使能信号控制，也就是说，这段代码每次写一个字节都要拉一次CS信号，效率比较低，我将 spi_enable 和 spi_disable 提出来后再次进行测试，速度确实有一定提升，但提升幅度仍然不大，只有大概几百ns的水平，优化效果仍然不理想。

这段代码只剩下两个函数了，ssp_writew 是写寄存器，根本不能优化，只能想办法优化 hi_spi_check_timeout，来看一下这个函数的实现
```
static int hi_spi_check_timeout(void)
{
    unsigned int value =  0;
    unsigned int tmp = 0;
    while (1)
    {
        ssp_readw(SSP_SR,value);
        if ((value & SPI_SR_TFE) && (!(value & SPI_SR_BSY)))
        {
            break;
        }

        if (tmp++ > MAX_WAIT)
        {
            printk("spi transfer wait timeout!\n");
            return -1;
        }
        udelay(1);
    }
    return 0;
}
```
逻辑非常简单，不停地读取发送FIFO空和SPI忙的标志位，延时1us继续读，直到发送完成且SPI空闲。看到这个 udelay(1) 你现在的想法肯定和我当时的想法一样：第一次读取发现寄存器没有置位，延时1us，第二次读取寄存器置位，退出循环，现在的发送间隔是1.6us，去掉这个延时尽快读取寄存器，应该直接能优化到0.6us以内。

想得美！实际测试去掉这个 udelay(1) 以后优化效果确实挺明显的，延时直接缩短到 1.2us 左右，但是这个延时还是太长了。

现在再来看这个函数，就剩一个读寄存器了，为了保证可靠传输，读标志位肯定不能去掉，这已经最简单了，还能怎么优化呢？我们重新梳理一下：去掉 udelay(1) 后间隔缩短到 1.2us 左右，说明这里循环读了很多次寄存器，不然怎么还有这么长的延时？那要不就加打印看看这里到底循环读取了几次？来来来，竞猜一下这里到底循环了几次？十次以内？百次以内？还是千次以内？答案是一次！没错只有一次！

1次这个答案可以说即在意料之外也在意料之中。
说它在意料之外是因为读写寄存器这种操作是非常快的，一般而言几个cpu时钟就能完成，但这里读一个寄存器却花费了 1.2us。
说它在意料之内是因为这些物理寄存器都是通过硬件置位的，以发送 FIFO 为空标志为例，当 SPI 发送完成瞬间它就会被硬件置位，这一点在任何一款单片机上都可以验证，实际操作一下就会发现类似的寄存器是瞬间被置位的。pl022 应该是非常成熟的 SPI 控制器，我觉得芯片设计人员不会犯发送 FIFO 为空后很长时间才设置标志位这种低级错误。

接下赖重点思考这个问题：为什么 ssp_readw(SSP_SR,value) 这样一个简单的读寄存器操作要 1.2us 之久？
（目前我测试 ssp_writew 写一个寄存器大概在 100ns 以内，ssp_readw 读一个寄存器大概在 1us 左右）
这个问题无论是百度还是谷歌我找了很久都没有找到确切答案，如果有知道的大佬非常欢迎指导！！！不白嫖知识，私信发红包。
下面是我个人的推测，虽然是推测，但我觉得这就是正确答案，仅供参考：

linux 不同于单片机裸机程序那样可以直接访问寄存器，如果需要读写物理寄存器，在内核态使用 `ioremap` （在用户态使用 `mmap`）将一段物理地址映射到内核态（或用户态）的虚拟地址空间，再对映射后的地址进行读写。

来看一下实际读写寄存器的这两个接口，很简单就是直接读写某个地址处的数据（前提是这个地址必须经过映射）。
```
#define  ssp_readw(addr,ret)       (ret =(*(volatile unsigned int *)(addr)))
#define  ssp_writew(addr,value)    ((*(volatile unsigned int *)(addr)) = (value))
```

首先可以明确一点，读写寄存器的操作必然会经过MMU。
对于写寄存器来说，不需要考虑同步、脏数据等问题，MMU 应该是直接将这个数据写到物理地址了。
对于读寄存器来说，有 `volatile` 关键字的存在，这里的代码不会去优化，每次读取必须从物理地址进行读取，这里可能需要 cache 回写等操作导致导致读取的速度非常慢。

在 u-boot 下可以直接读写物理寄存器，应该不需要这么久，几个CLK就可以完成吧？这一点我没有验证过，有测试过的朋友欢迎分享。

总之，耗时的地方找到了，想办法优化吧。我这里有两种优化思路：
1. 查阅手册可知，SPI的内部收发部分各有一个宽度 16bit、深度为 256 的 FIFO。我可以一次性写入不超过256字节的数据，然后使用 ssp_readw 不停地读取寄存器，直到发送 FIFO 为空。在50MHz时钟的条件下情况下 ssp_readw 的 1.2us 延时相当于发送了8字节左右，理论上来说如果发送的数据量大于8字节，这个 1.2us 延时等于没有。
2. 每次发送1字节，加适当延时，保证发送相邻两字节之间的间隔尽量短。

目前我采用的就是第二种方法，第一种方法就留给大家验证并开发吧（其实就是我懒）。
来看一下我的现实代码：
```
void hi_spi_delay(void)
{
    volatile unsigned int tmp = 0;
    while (tmp++ < 30);
}

void spi_write_byte(unsigned char dat)
{
    unsigned short spi_data = 0;
    spi_data = dat;
    ssp_writew(SSP_DR, spi_data);
    hi_spi_delay();
}
```
这个延迟函数一定要根据编译器、CPU主频、SPI时钟频率等实际测量后进行调整。经过我的反复调整和测量，最终把循环计数设置为了30，来看一下示波器抓到的波形


间隔 65ns，也就是每字节耗时 225us，大约相当于 36MHz 的SPI时钟频率。

改成其他值行不行呢？这是我的测量结果
* 30 可以保证在50MHz时钟下，每两字节之间间隔 65ns，
* 32 可以保证在50MHz时钟下，每两字节之间间隔 80ns，
* 35 可以保证在50MHz时钟下，每两字节之间间隔 100ns，
但是，重点来了！循环计数小于29或不加延时的间隔是 60ns，似乎达到了某种限制，具体原因没找到，我担心有丢数据的风险，所以将循环计数设置为了30，这个值也正好是可以明显观察到延时函数有效的最小值，SPI 速率虽然没有真正达到理论值，但是对于目前的使用场景来说已经足够了。

前面说了，延时函数一定要根据实际情况进行修改，确保每字节之间有一定间隔。假设你换了海思的另外一款芯片，或者使用了其他基于 ssp-pl022 控制器的芯片，也遇到了类似的 SPI 速率低的问题，但手头没有示波器进行测量怎么办？假设你所使用的芯片提供了精确到10ns的延时函数，直接拿来用就行。没有这样的函数没关系，可以做一个简单的估算，估算结果与实际肯定有偏差，但不管怎么说这个数值也算比较靠谱的。我们来一步一步分析这个延时函数如何实现。

首先是 `volatile` 关键字，开发调试期间为了方便分析问题，编译优化选项往往设置为 `-O0`，不论加不加这个关键字都没问题，但正式程序的编译优化选项一般都会设置为`-O2`，`-Os`，`-O3`，这种情况下编译器会直接把这个函数优化掉，所以必须加 `volatile` 关键字。

确定好你所使用的编译器和编译优化参数，有的芯片厂商会提供多个版本的编译器，或者后来编译器更新了，编译器不同可能会导致代码行为不同，编译优化参数不同也会导致代码行为不同，假设最终发布代码使用`-Os`，那么测试期间也使用`-Os`，总之确定好这两点，在之后的开发过程中不要更改。

确定好你的延时函数的循环怎么写，包括但不限于
```
while (tmp++ < 30);

tmp = 30
while(1) {if(tmp-- == 0){break;}};

tmp = 30
while (tmp--);

for (tmp=0; tmp<30; tmp++);
```
无论怎么写都能达到延时的作用，有的编译器可能非常聪明，发现循环中什么都没做，最终这4种写法都被优化成了相同的汇编代码，但有的编译器可能不会，总之你不能保证编译器会把他们优化成相同的汇编代码，所以确定了延时函数的写法以后在之后的开发过程中不要更改。

下一步将循环计数设置为比较大的数，例如十万，一百万，执行这个函数并计算耗时，不论是用秒表，还是用 gettimeofday，或者是 time 命令，总之最终目的是算出1个循环耗时多少。假设我测量出循环百万次耗时5.3ms，那么循环一次耗时就是5.3ns。向上取整按一次循环耗时6ns计算，为什么这样做？自己想。

假设 SPI 的时钟速率是50MHz，发送数据位宽是 8bit，则发送1次耗时 `1s / 50MHz * 8 = 160ns`，延时循环的次数为 `160 / 6 = 26.6`，向上取整为27次。考虑到函数调用的耗时、读写寄存器的耗时等，实际两次发送之间的间隔肯定比它略长，但无论怎么说，27 就是我们估算出来的延时循环计数。

当然还有更靠谱一点的估算方法。目前我的延时函数及对应的汇编代码如下：
```
void hi_spi_delay(void)
{
    volatile unsigned int tmp = 0;
    while (tmp++ < 30);
}

Dump of assembler code for function hi_spi_delay:
   0x00010454 <+0>:  mov r3, #0
   0x00010458 <+4>:  sub sp, sp, #8
   0x0001045c <+8>:  str r3, [sp, #4]
   0x00010460 <+12>: ldr r3, [sp, #4]
   0x00010464 <+16>: cmp r3, #29
   0x00010468 <+20>: add r3, r3, #1
   0x0001046c <+24>: str r3, [sp, #4]
   0x00010470 <+28>: bls 0x10460 <hi_spi_delay+12>
   0x00010474 <+32>: add sp, sp, #8
   0x00010478 <+36>: bx  lr
End of assembler dump.
```

循环体对应的就是这5句
```
   0x00010460 <+12>: ldr r3, [sp, #4]
   0x00010464 <+16>: cmp r3, #29
   0x00010468 <+20>: add r3, r3, #1
   0x0001046c <+24>: str r3, [sp, #4]
   0x00010470 <+28>: bls 0x10460 <hi_spi_delay+12>
```
我所使用的芯片采用Cortex-A7架构，我实在没找到它的指令周期的文档，这里用Cortex-A9的替代一下，ARM官网文档如下 https://developer.arm.com/documentation/ddi0388/f/Instruction-Cycle-Timings?lang=en ，跳转指令的周期是不确定的，其他4个指令的都是单周期指令，循环中大多情况都是跳转，只有最后一次是不跳转，我们也按单周期计算好了。由此可知，循环一次需要5个周期，CPU的主频是900MHz，假设CPU主频固定，不超频，也不降频进入低功耗模式，那么循环一次耗时 `1s / 900MHz * 5 = 5.55ns`，这可以说是一个很精确的值了，同样的条件下可以算出需要的循环次数为 `160 / 5.55 = 28.8`，向上取整为29次。是不是和我目前使用的循环计数30基本一致？

好了，到此为止开发过程中遇到的问题还有我自己的疑惑都讲完了，有问题欢迎大家讨论。

如果你有朋友正好在海思工作，请将本文转发给他，我不知道海思其他产品线的芯片会不会也有这个问题。我这样写的代码多少有些随意，希望海思官方能优化一下 SPI 的速率问题。

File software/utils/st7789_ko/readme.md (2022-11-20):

这是根据海思SDK内 drv.tgz\drv\extdrv\ssp-st7789 修改而来的 st7789 内核驱动
如有引脚改动、寄存器修改等，则必须重新配置相关内容并重新编译本内核模块
编译内核驱动依赖内核源文件，请参考海思相关手册搭建完整开发环境

编译方法如下：
1. 在搭建好开发环境以后，将本文件夹拷贝到`Hi3516EV200_SDK_V1.0.1.2/drv/extdrv/`中
2. 在 `extdrv/` 目录中输入 `make` 进行编译
3. 编译产物在 `extdrv/` 中各自文件夹内

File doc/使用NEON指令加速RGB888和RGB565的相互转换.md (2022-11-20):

本项目需要将RGB888转换为RGB565，用C语言转换的代码很简单，这是从ffmpeg中摘抄的代码
```
static inline void rgb24to16_c(const uint8_t *src, uint8_t *dst, int src_size)
{
    uint16_t *d        = (uint16_t *)dst;
    const uint8_t *s   = src;
    const uint8_t *end = s + src_size;

    while (s < end) {
        const int r = *s++;
        const int g = *s++;
        const int b = *s++;
        *d++        = (b >> 3) | ((g & 0xFC) << 3) | ((r & 0xF8) << 8);
    }
}
```

项目中需要转换的数据量不多，用C语言进行转换的CPU开销完全可以接受。但我并不满足于此，芯片支持NEON指令加速，所以为什么不用呢？

简单搜索一番发现国很少有相关的文章，最后还是去外面找了一些有用的资料，在学习NEON指令和寻找的过程中发现ARM官网已经提供了例程，那我正好可以偷懒。

这里给出ARM官网的例程链接，防止有人无法无访问，这里也给出源码
RGB888转RGB565
https://developer.arm.com/documentation/den0018/a/NEON-Code-Examples-with-Optimization/Converting-color-depth/Converting-from-RGB888-to-RGB565
```
uint8_t *src = image_src;
uint16_t *dst = image_dst;
int count = PIXEL_NUMBER;

while (count >= 8) {
    uint8x8x3_t vsrc;
    uint16x8_t vdst;

    vsrc = vld3_u8(src);

    vdst = vshll_n_u8(vsrc.val[0], 8);
    vdst = vsriq_n_u16(vdst, vshll_n_u8(vsrc.val[1], 8), 5);
    vdst = vsriq_n_u16(vdst, vshll_n_u8(vsrc.val[2], 8), 11);

    vst1q_u16(dst, vdst);

    dst += 8;
    src += 8*3;
    count -= 8;
}
```

RGB565转RGB888
https://developer.arm.com/documentation/den0018/a/NEON-Code-Examples-with-Optimization/Converting-color-depth/Converting-from-RGB565-to-RGB888
```
uint16_t *src = image_src;
uint8_t *dst = image_dst;
int count = PIXEL_NUMBER;

while (count >= 8) {
    uint16x8_t vsrc;
    uint8x8x3_t vdst;

    vsrc = vld1q_u16(src);

    vdst.val[0] = vshrn_n_u16(vreinterpretq_u16_u8(vshrq_n_u8(vreinterpretq_u8_u16(vsrc), 3)), 5);
    vdst.val[1] = vshl_n_u8(vshrn_n_u16(vsrc, 5) ,2);
    vdst.val[2] = vmovn_u16(vshlq_n_u16(vsrc, 3));

    vst3_u8(dst, vdst);

    dst += 8*3;
    src += 8;
    count -= 8;
  }
```

NEON的头文件是 `arm_neon.h`，查阅海思SDK内相关文档可知编译需要加 `-mcpu=cortex-a7 -mfloat-abi=softfp -mfpu=neon-vfpv4`。
接下来就是传统项目，性能测试，随机生成数据的 RGB888 图片转换为 RGB565 图片，重复1000次并计时，测试代码如下
```
#include <arm_neon.h>
#include <stdio.h>
#include <stdint.h>
#include <string.h>
#include <stdlib.h>
#include <unistd.h>

void rgb888_to_rgb565(uint8_t *in, uint8_t *out, int h, int v)
{
    uint16_t *d        = (uint16_t *)out;
    const uint8_t *s   = in;
    const uint8_t *end = s + h * v * 3;

    while (s < end) {
        const int r = *s++;
        const int g = *s++;
        const int b = *s++;
        *d++        = (b >> 3) | ((g & 0xFC) << 3) | ((r & 0xF8) << 8);
    }
}

void rgb888_to_rgb565_neon(uint8_t *in, uint8_t *out, int h, int v)
{
    uint8_t *src = in;
    uint16_t *dst = (uint16_t *)out;
    int count = h * v;

    if (count % 8 != 0) {
        printf("pixel number must align with 8\n");
        return;
    }

    while (count >= 8) {
        uint8x8x3_t vsrc;
        uint16x8_t vdst;

        vsrc = vld3_u8(src);

        vdst = vshll_n_u8(vsrc.val[0], 8);
        vdst = vsriq_n_u16(vdst, vshll_n_u8(vsrc.val[1], 8), 5);
        vdst = vsriq_n_u16(vdst, vshll_n_u8(vsrc.val[2], 8), 11);

        // 实际应用中还需要将大端转换为小端，所以加了这一句，性能测试中这一句去掉了
        // vdst = (uint16x8_t)vrev16q_u8((uint8x16_t)vdst);
        vst1q_u16(dst, vdst);

        dst += 8;
        src += 8*3;
        count -= 8;
    }
}

#define WIDTH 320
#define HEIGHT 180

// #define WIDTH 640
// #define HEIGHT 360

// #define WIDTH 960
// #define HEIGHT 540

// #define WIDTH 1280
// #define HEIGHT 720

// #define WIDTH 1600
// #define HEIGHT 900

// #define WIDTH 1920
// #define HEIGHT 1080

#define LOOP 1000

uint8_t rgb888[WIDTH * HEIGHT * 3];
uint16_t rgb565[WIDTH * HEIGHT];
int main(int argc, char **argv)
{
    int32_t i;
    for (i = 0; i < WIDTH * HEIGHT * 3; i++) {
        rgb888[i] = rand() & 0xFF;
    }

    struct timeval tv1;
    struct timeval tv2;
    double td = 0; // ms

    printf("size %d x %d, loop %d\n", WIDTH, HEIGHT, LOOP);

    gettimeofday(&tv1, NULL);
    for (i = 0; i < LOOP; i++) {
        rgb888_to_rgb565(rgb888, (uint8_t *)rgb565, WIDTH, HEIGHT);
    }
    gettimeofday(&tv2, NULL);
    td = ((double)tv2.tv_sec * 1000.0 + (double)tv2.tv_usec / 1000.0) - ((double)tv1.tv_sec * 1000.0 + (double)tv1.tv_usec / 1000.0);
    printf("time c: %f ms\n", td);

    gettimeofday(&tv1, NULL);
    for (i = 0; i < LOOP; i++) {
        rgb888_to_rgb565_neon(rgb888, (uint8_t *)rgb565, WIDTH, HEIGHT);
    }
    gettimeofday(&tv2, NULL);
    td = ((double)tv2.tv_sec * 1000.0 + (double)tv2.tv_usec / 1000.0) - ((double)tv1.tv_sec * 1000.0 + (double)tv1.tv_usec / 1000.0);
    printf("time neon: %f ms\n", td);

    return 0;
}
```

来看一下耗时：
```
size 320 x 180, loop 1000
time c: 1049.035889 ms
time neon: 405.596924 ms

size 640 x 360, loop 1000
time c: 3948.885986 ms
time neon: 2150.033203 ms

size 960 x 540, loop 1000
time c: 9026.308838 ms
time neon: 5033.337891 ms

size 1280 x 720, loop 1000
time c: 16550.081055 ms
time neon: 8756.577881 ms

size 1600 x 900, loop 1000
time c: 25366.738037 ms
time neon: 13618.843994 ms

size 1920 x 1080, loop 1000
time c: 37058.665039 ms
time neon: 20064.520996 ms
```
对于RGB888转RGB565来说，NEON指令的性能大约是C语言的两倍。其他NEON指令的性能未做测试，以上测试内容仅供参考。

最后给出ARM官方的参考文档
NEON指令开发指南
https://developer.arm.com/documentation/den0018/a

NEON指令查询
https://developer.arm.com/architectures/instruction-sets/intrinsics/#f:@navigationhierarchiessimdisa=[Neon]

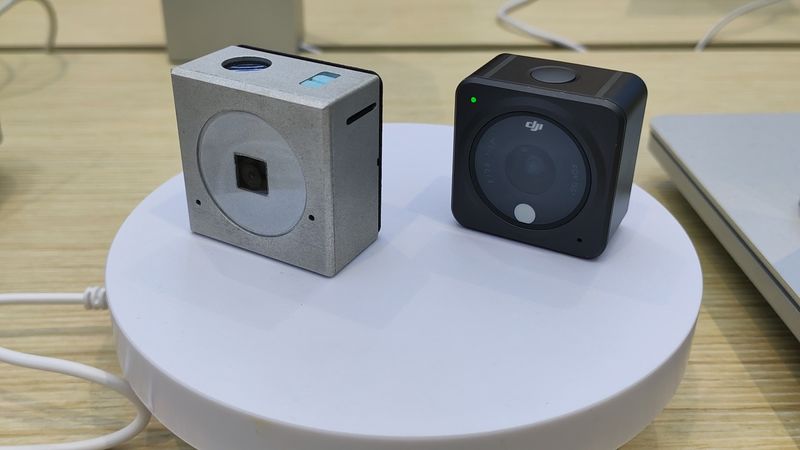
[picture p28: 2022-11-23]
doc/img/article/封面.jpg

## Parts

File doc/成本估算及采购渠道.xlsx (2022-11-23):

型号 | 单价 | 数量 | 总价 | 备注
其他器件 （容阻感、DC电源、接插件、FPC排线等） | 50 | 1 | 50 | 如果自己已购买了一些元件，这里的花费比较小，反之较高 如果打算使用SMT，这部分成本可以算在SMT中
mpu6050 | 30 | 1 | 30 | 1.立创 C24112 价格有波动，按80计算，当然以后也许会降价吧 2.淘宝货源，模块或单芯片价格在5到20元不等 综上，这里暂且按30元计算
w25q128 | 6 | 1 | 6 | 立创 C97521
3516ev200 | 30 | 1 | 30 | 1.闲鱼购买二手拆机摄像头，这种不包好坏，完全看运气，然后自己拆芯片，价格20到50不等，超过50就是奸商 2.购买全新库存摄像头模组，这种模组都是可以正常使用，因此价格较贵，一般在40到150不等。 3.全新库存芯片。能买到最好，反正我没买到，具体价格也不知道，姑且算40吧。
镜头膜 | 7 | 1 | 7 | 淘宝购买任意DJI Action 2镜头膜即可，价格仅供参考，不同厂家镜头膜直径略有不同，但都在28mm至30mm之间
镜头 | 21 | 1 | 21 | 金属壳带自动对焦的OV5640视场角比较小，一般为68度，不推荐。 淘宝上只有“独具匠心之家”卖96度视角的OV5640
显示屏 | 12 | 1 | 12 | 1.33寸ips液晶屏，spi接口。渠道：淘宝中景园企业店
触摸屏 | 7 | 1 | 7 | 淘宝只有“深圳市迈高达科技有限公司”这家店卖1.54寸触摸屏
电池 | 10 | 1 | 10
喇叭 | 1 | 1 | 1 | 1510喇叭，淘宝上随便买
iPhone按键 | 2 | 1 | 2 | 任意渠道购买4s、5、5c、6、6p的按键即可，这几款都是不带指纹的，按键的直径完全一样，价格也是最便宜的。6s及其他型号的按键带有指纹功能，价格更贵，不推荐。
其他 | 50 | 1 | 50 | 如胶带、胶水、螺丝、散热帖等
总计 |  |  | 226
贴片成本（不含换料费） | 单价 | 数量 | 总价 | 备注
主板2片贴背面 | 35 | 2 | 70 | 只贴阻容、磁珠，不贴其他任何芯片、连接器、功率电感等，约50+10*2
主板5片贴背面 | 20 | 5 | 100 | 只贴阻容、磁珠，不贴其他任何芯片、连接器、功率电感等，约50+10*5
主板2片贴双面 | 250 | 2 | 500 | 不贴3516和6050，其余阻容、芯片、连接器等全贴，约400+50*2
主板5片贴双面 | 125 | 5 | 625 | 不贴3516和6050，其余阻容、芯片、连接器等全贴，约400+45*5
外壳成本 | 单价 | 数量 | 总价 | 备注
CNC外壳 | 240 | 1 | 240 | 三维猴，工艺不同价格略有不同，一般在220到250之间
3D打印外壳 | 25 | 1 | 25 | 三维猴，黑色尼龙的价格，在20到25左右
成本 | 3D打印 | CNC
不贴片 | 251 | 466
主板2片贴背面（单台） | 286 | 501
主板5片贴背面（单台） | 271 | 486
主板2片贴双面（单台） | 501 | 716
主板5片贴双面（单台） | 376 | 591
主板2片贴背面（2台） | 346 | 776
主板5片贴背面（5台） | 451 | 1526
主板2片贴双面（2台） | 776 | 1206
主板5片贴双面（5台） | 976 | 2051
以下三种焊接方案，大家可以视自己的焊接能力（钞能力）酌情选择 1.全手工焊接：开钢网的话还行，不开钢网的话不推荐手焊。元件数量多，焊接过程容易出错，一不小心就5A大电流 2.只贴背面：少花一点钱，而且可以节省不少精力（只贴背面的阻容、磁珠，贴除此以外的其他任何器件都会导致费用明显增加） 3.全贴：方便快捷，拿到手只需焊个主控，土豪的选择 备注：为了尽可能降低贴片费用，所有贴片元件能用立创基础库的都已修改为基础库

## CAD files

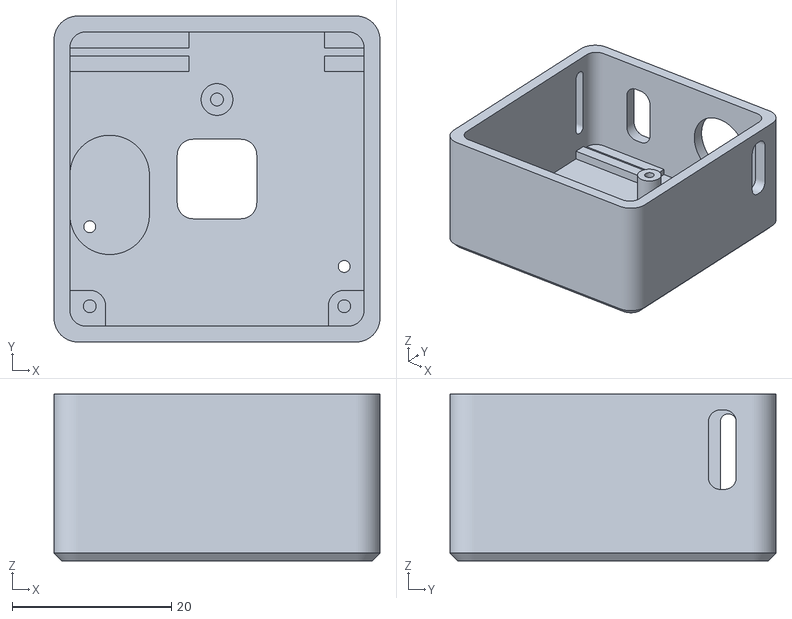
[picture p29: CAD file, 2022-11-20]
hardware/model/3dp_shell/shell1.stl
41.0 x 41.0 x 21.0

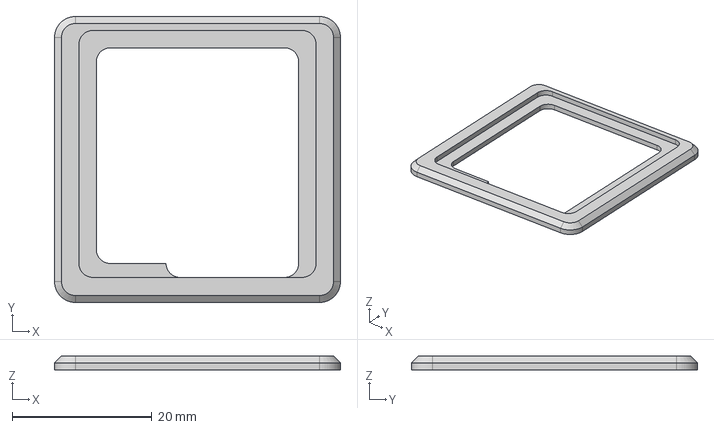
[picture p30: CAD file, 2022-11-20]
hardware/model/cnc_shell/shell3.step
41.0 x 41.0 x 2.00 mm

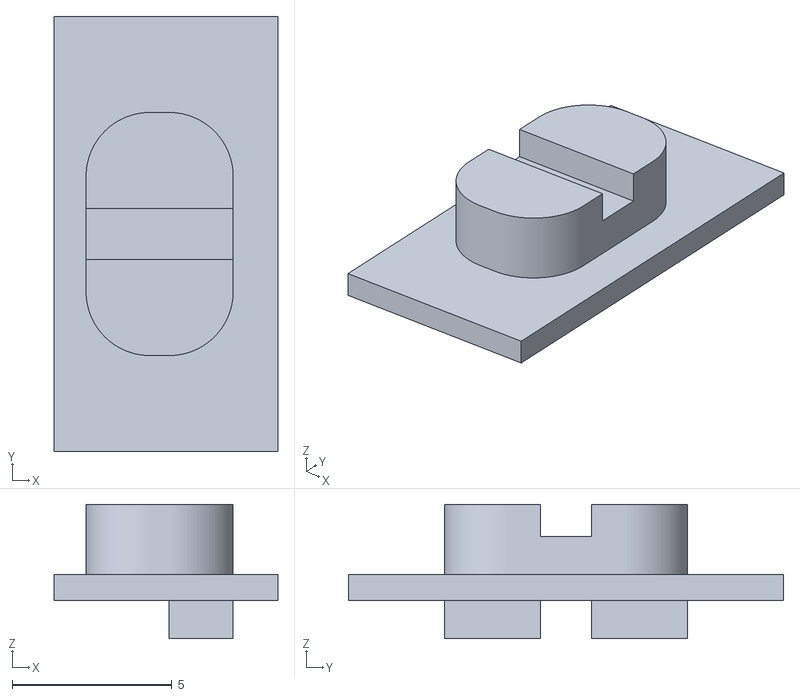
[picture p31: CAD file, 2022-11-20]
hardware/model/switch/switch.stl
7.00 x 13.6 x 4.20

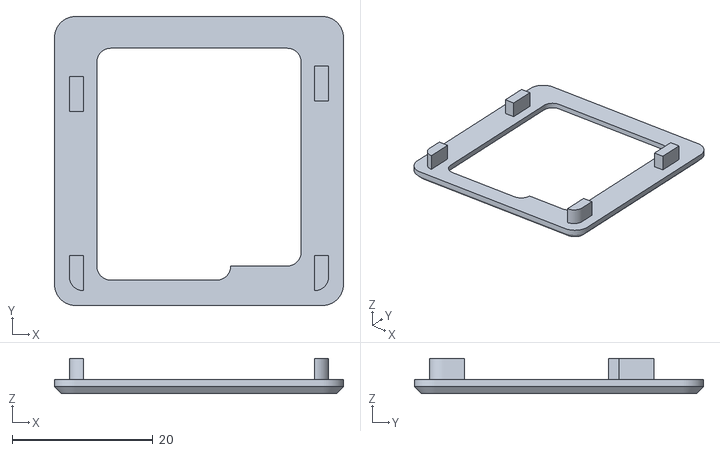
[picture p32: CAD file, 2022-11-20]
hardware/model/3dp_shell/shell2.stl
41.0 x 41.0 x 5.00

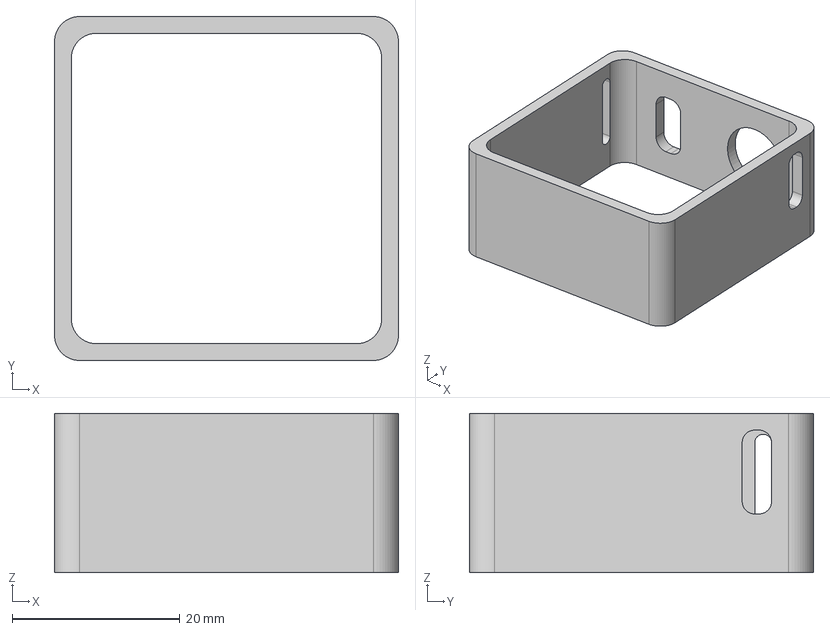
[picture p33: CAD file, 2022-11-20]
hardware/model/cnc_shell/shell2.step
41.0 x 41.0 x 19.0 mm

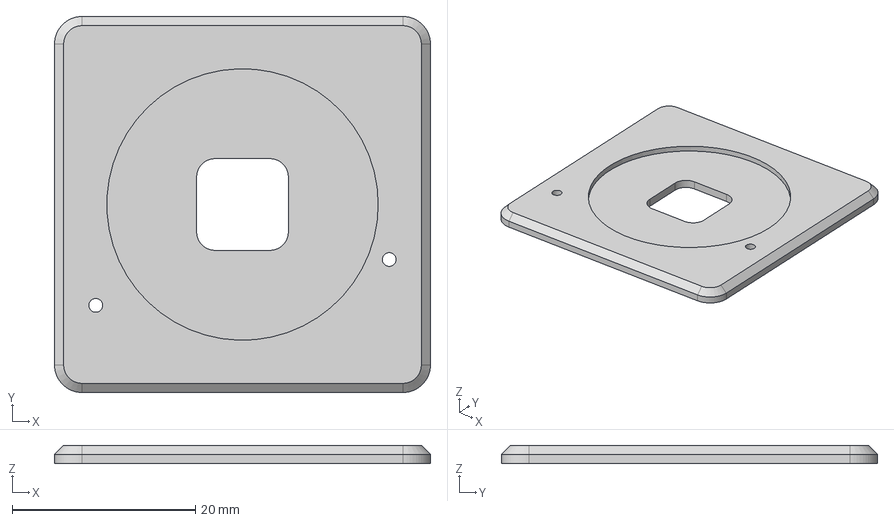
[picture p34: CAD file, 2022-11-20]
hardware/model/cnc_shell/shell1.step
41.0 x 41.0 x 2.00 mm

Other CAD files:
hardware/model/3dp_shell/Action_2_Poor_3DP.f3d
hardware/model/cnc_shell/Action_2_Poor_CNC_v2.f3d
hardware/model/switch/switch.f3d

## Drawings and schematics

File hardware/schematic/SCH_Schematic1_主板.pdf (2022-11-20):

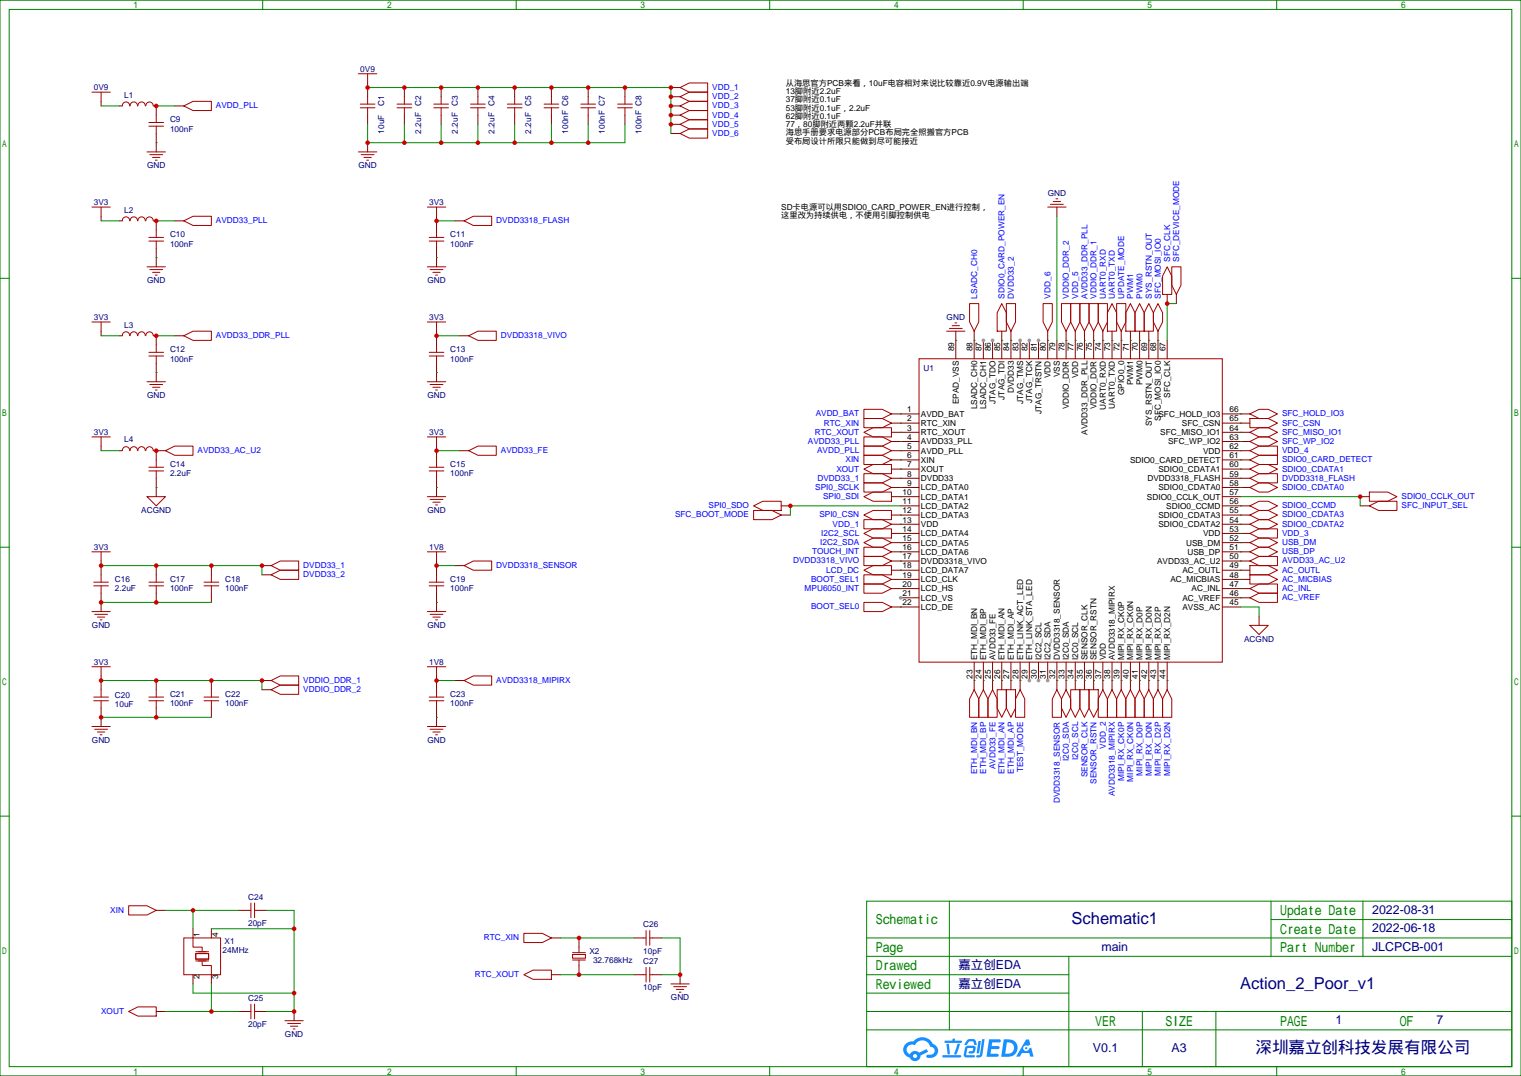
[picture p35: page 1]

## 上电延迟计算公式 Vcc电源电压，V0电容初始电压，Vt为t时刻电压

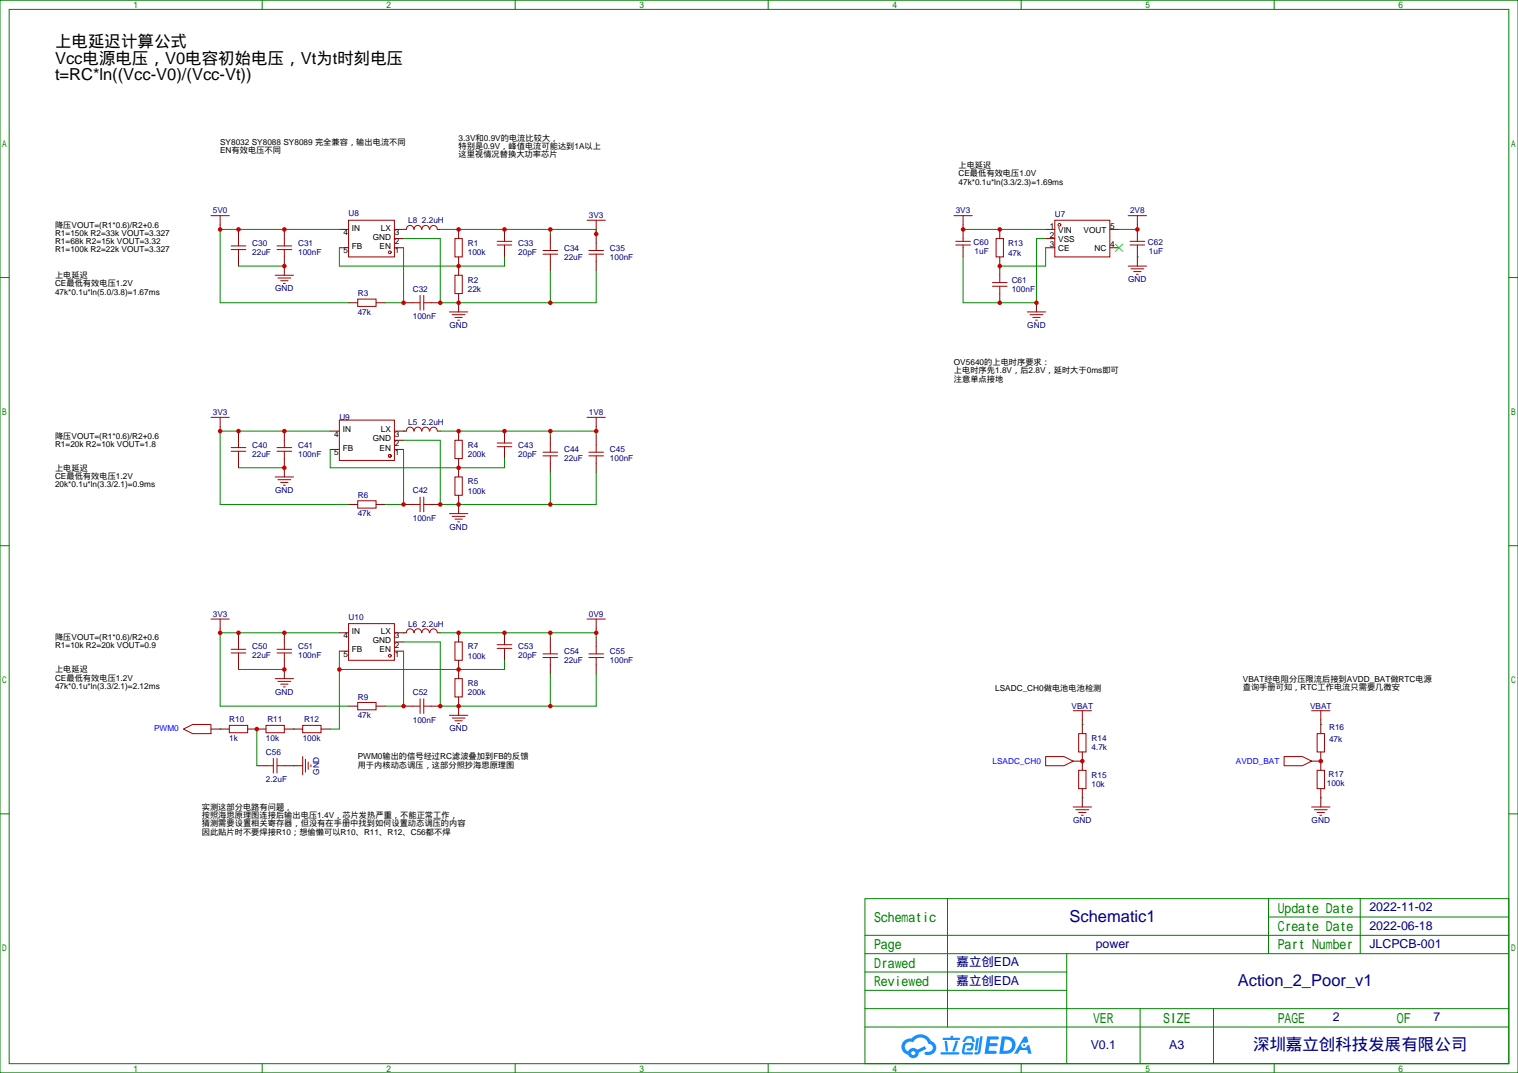
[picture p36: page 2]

t=RC*ln((Vcc-V0)/(Vcc-Vt))

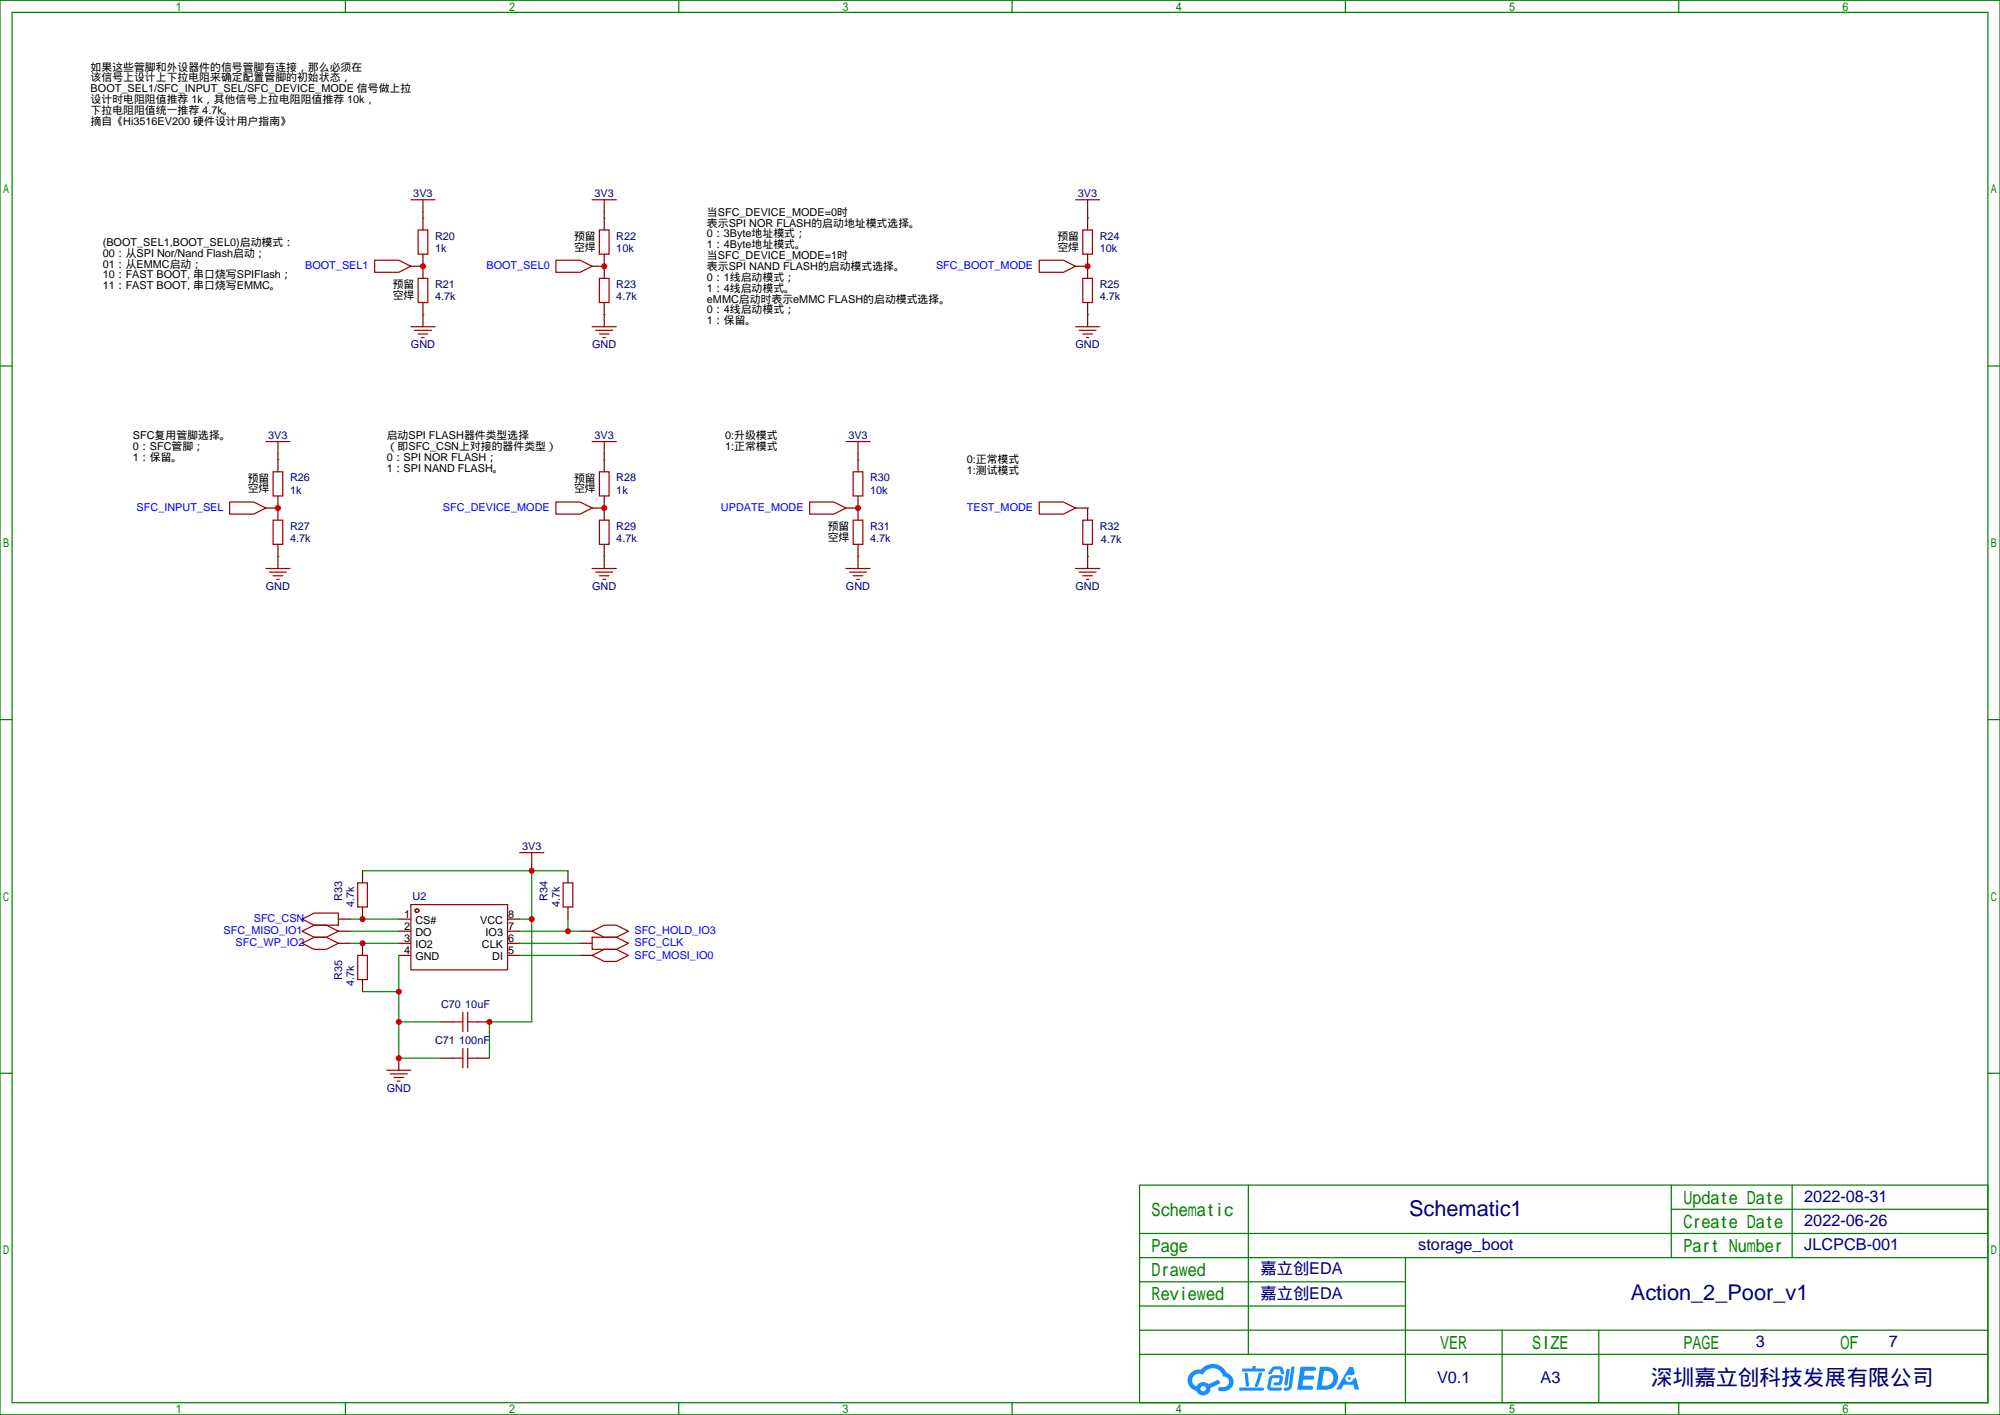
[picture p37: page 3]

(BOOT_SEL1,BOOT_SEL0)启动模式：
00：从SPI Nor/Nand Flash启动；
01：从EMMC启动；
10：FAST BOOT, 串口烧写SPIFlash；

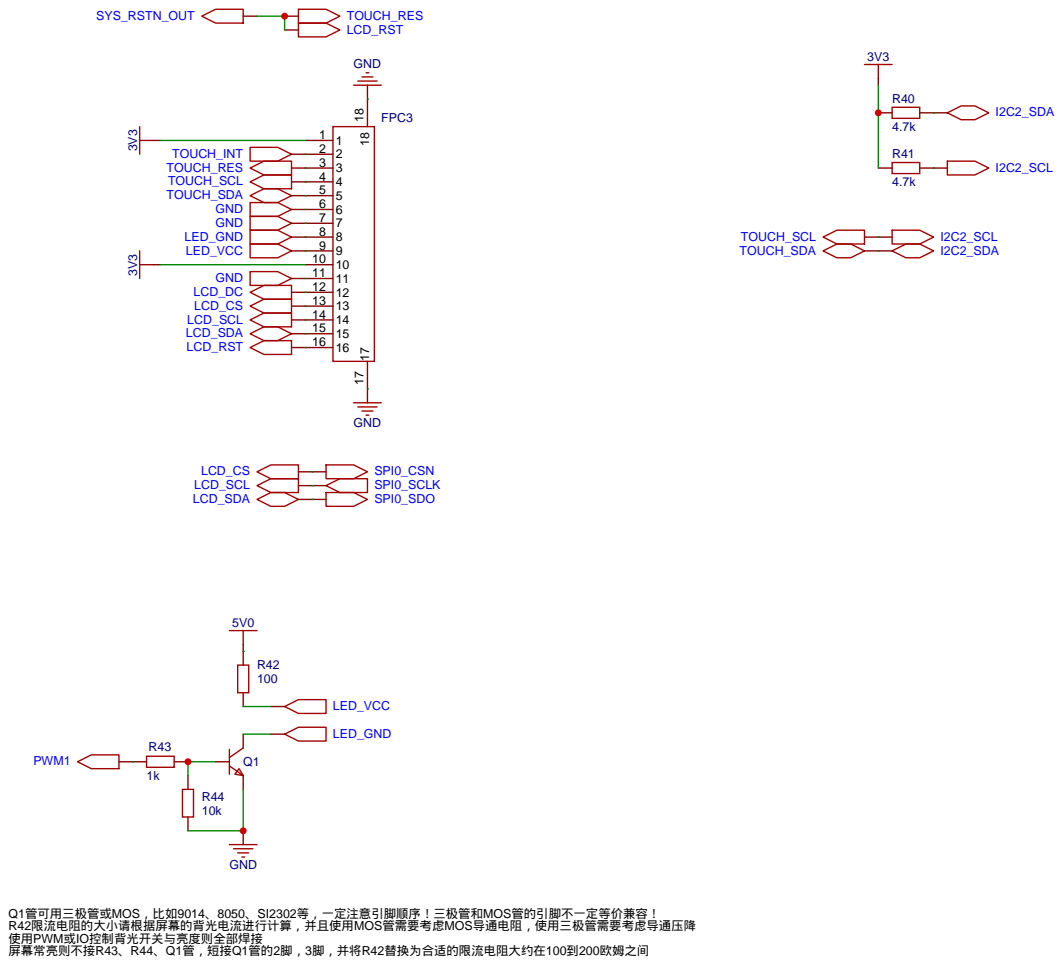
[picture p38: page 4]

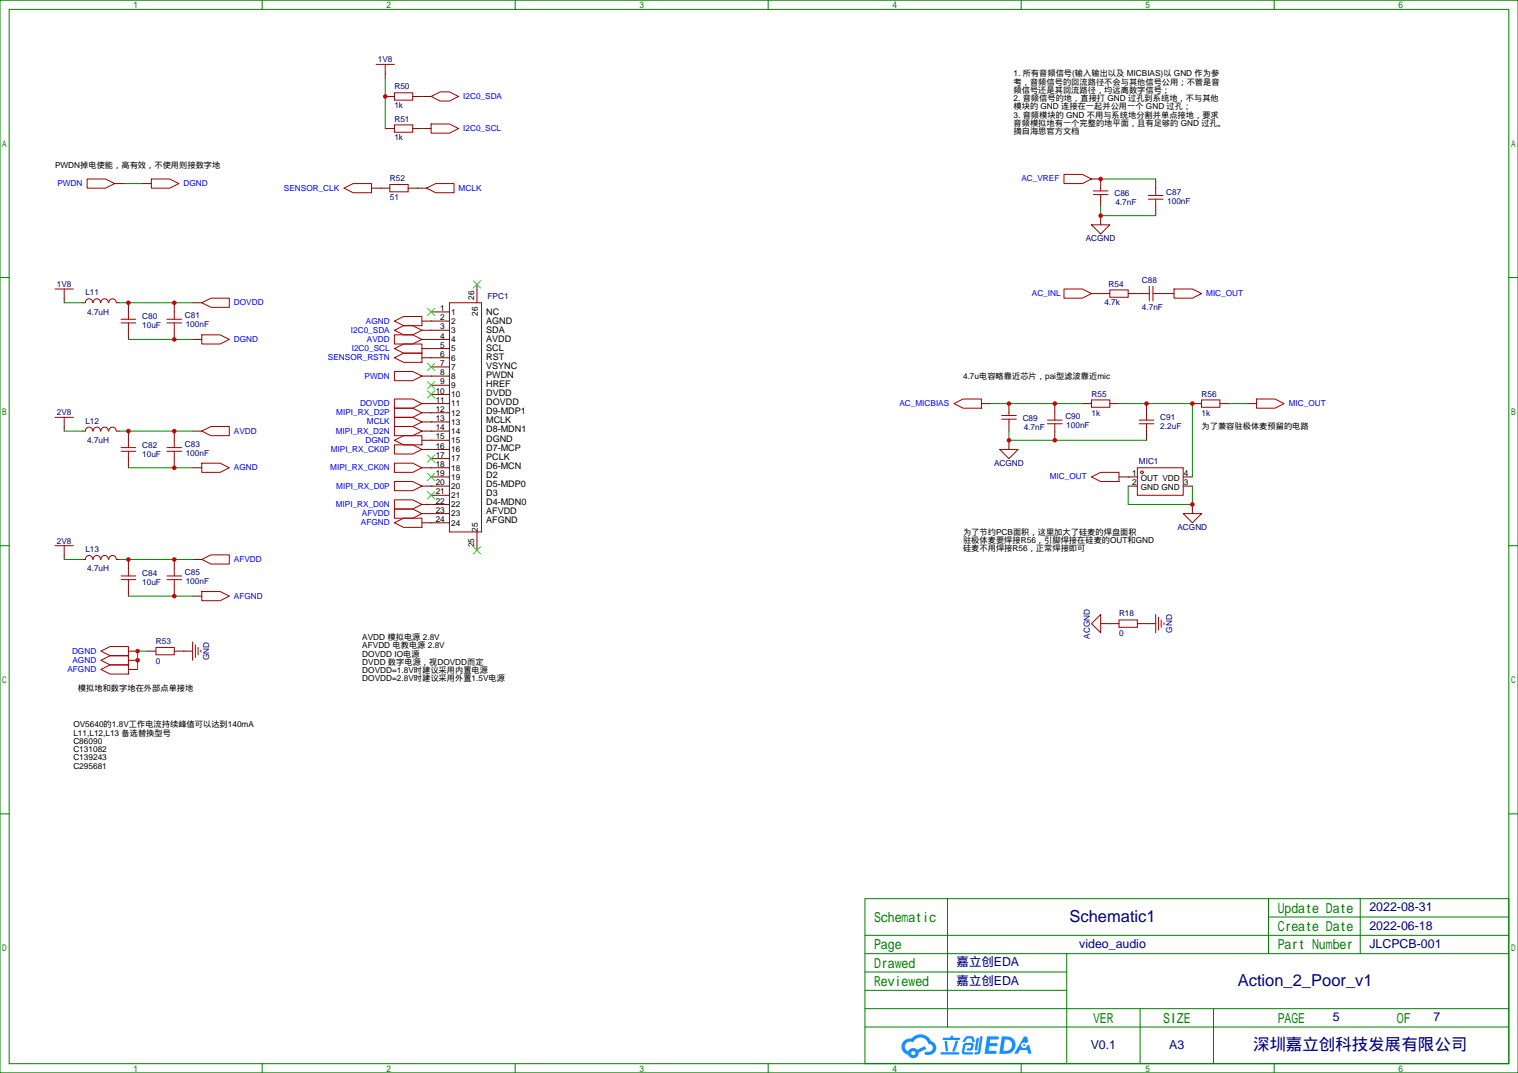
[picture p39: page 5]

1. 所有音频信号(输入输出以及 MICBIAS)以 GND 作为参
考，音频信号的回流路径不会与其他信号公用；不管是音
频信号还是其回流路径，均远离数字信号；
2. 音频信号的地，直接打 GND 过孔到系统地，不与其他
模块的 GND 连接在一起并公用一个 GND 过孔；
3. 音频模块的 GND 不用与系统地分割并单点接地，要求
音频模拟地有一个完整的地平面，且有足够的 GND 过孔。
摘自海思官方文档

## 3V3GND

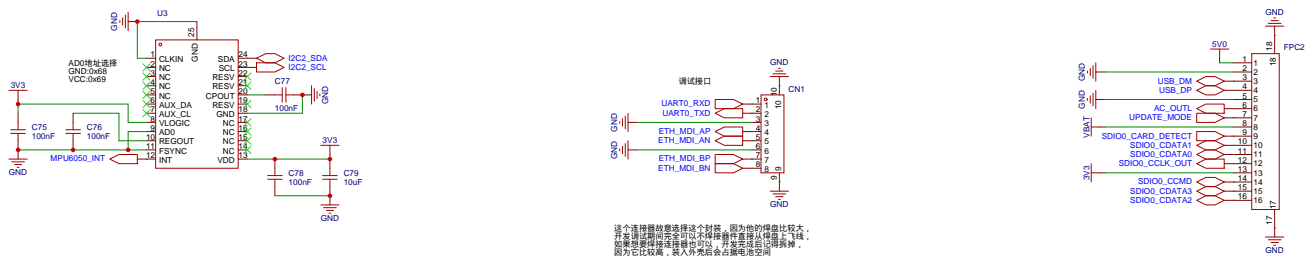
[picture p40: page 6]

## 主板元件密集，因此在上下两侧添加工艺边，并在工艺边上添加SMT的定位孔和光学点位点

## MIPI信号线、USB信号线需要阻抗匹配，但是我没做（连上就行，又不是不能用，无非就是信号差一点，狗头.jpg。其实是个人能力有限，希望有大佬能指点一二！）

## 主控的封装为 QFN-88_L9.0-W9.0-P0.35-BL-EP5.26，立创提供的封装引脚太短，无法手工焊接，本原理图中专门加长了引脚，MPU6050的封装同样加长引脚

## 3.3V和0.9V需要的功率较大，建议选用输出电流1.5A以上的芯片，1.8V需要的功率较小，使用输出电流1A的芯片就可以

## 不是每个人都舍得用SMT，因此为了尽可能方便手工焊接，我尽量选用了0603的封装。 目前电容全部采用0603及以上封装，对于焊接后续不会修改的电阻采用0402封装，对于boot相关电阻，为方便后续修改采用0603封装

## 所有容阻元件均已替换为基础库元件，SMT生产科节约换料费，基础库元件查询网址

# https://www.jlc.com/portal/smtComponentList.html

## 以下元件默认不加入BOM，如需SMT一定记得修改 电源相关

# C56 R10 R11 R12 BOOT相关 R21 R22 R24 R26 R28 R31

## 音频相关

R56
芯片
U1

## 接插件

CN1

### Reviewed

### Drawed

### Create Date Part Number

### Schematic

### Update Date

### Page

嘉立创EDA
嘉立创EDA

## JLCPCB-001

# Action_2_Poor_v1

2022-11-14
2022-06-18

# Schematic1

## doc

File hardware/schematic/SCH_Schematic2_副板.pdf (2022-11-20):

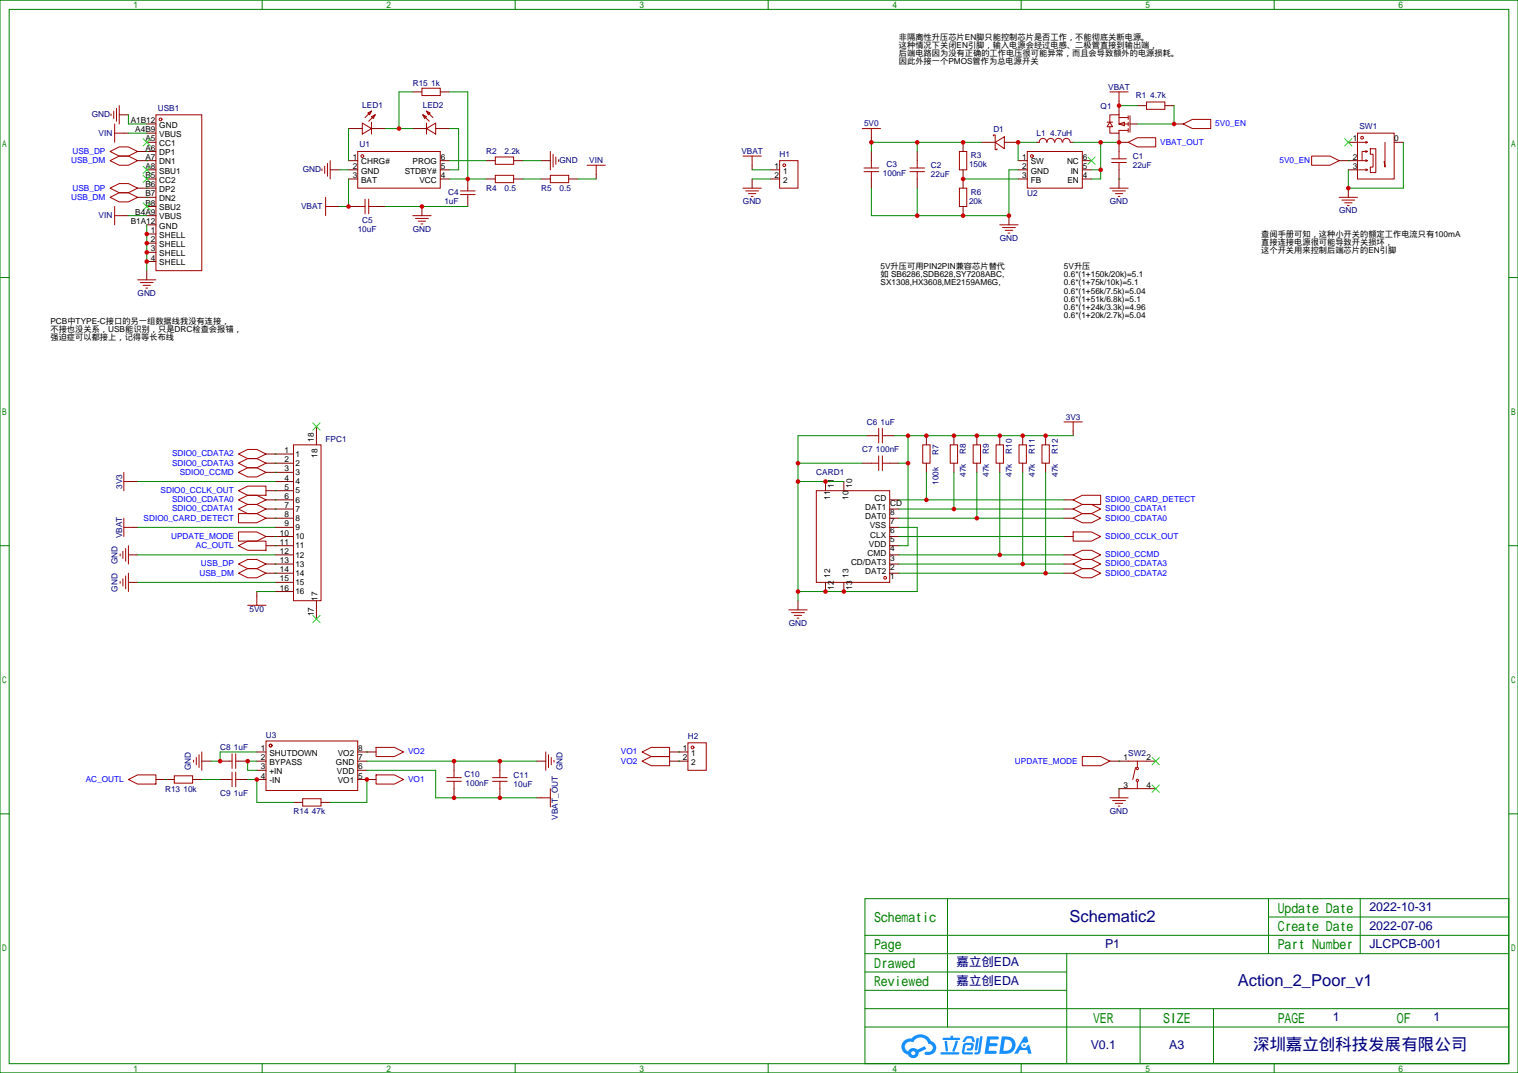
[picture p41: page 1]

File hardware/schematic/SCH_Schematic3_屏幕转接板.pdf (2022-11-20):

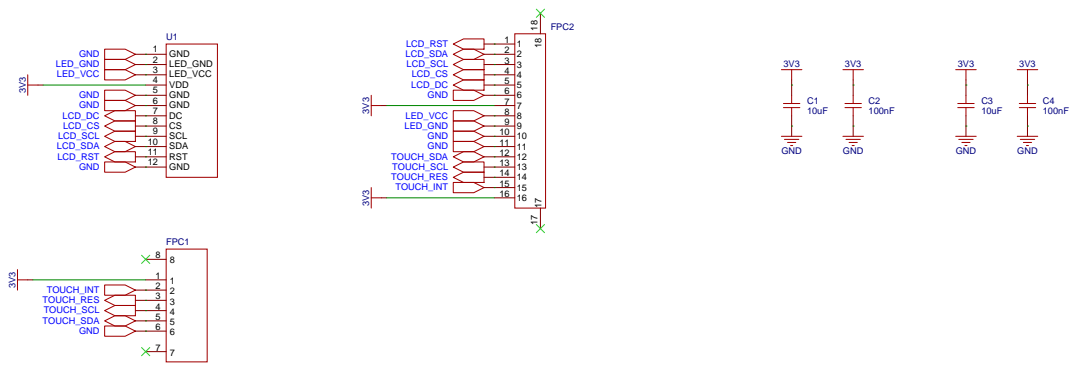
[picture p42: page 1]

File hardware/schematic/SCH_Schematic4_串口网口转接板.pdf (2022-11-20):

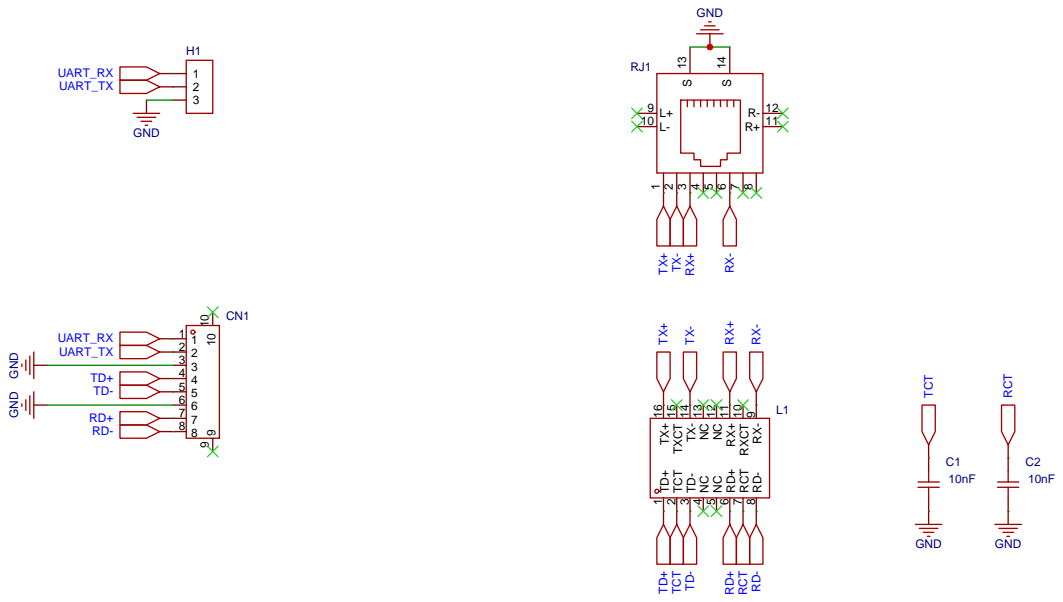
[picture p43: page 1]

9 RXCT 10 RX+ 11 NC 12 NC 13 TX- 14 TXCT 15 TX+ 16

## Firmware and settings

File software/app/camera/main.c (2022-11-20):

#include <signal.h>

#include <stdint.h>
#include <stdio.h>
#include <stdlib.h>
#include <string.h>
#include <pthread.h>
#include <sys/prctl.h>
#include <sys/time.h>
#include <time.h>
#include <unistd.h>
#include <sys/ioctl.h>
#include <fcntl.h>

#include "himm.h"
#include "i2c.h"
#include "ft6206.h"
#include "ssp_st7789.h"
#include "lvgl.h"
#include "cam_gui.h"
#include "key.h"
#include "mpu6050.h"
#include "gyroflow_log.h"
#include "file_opt.h"
#include "hisi_adc.h"
#include "cJSON.h"
#include "himpp.h"
#include "camera_himpp_config.h"
#include "camera_base_config.h"
#include "media.h"

#define LCD_SCREEN_WIDTH  (240)
#define LCD_SCREEN_HEIGHT (240)

#define JSON_CONFIG_FILE_NAME "./config.json"

#define JSON_ITEM_VFORMAT  "format"
#define JSON_ITEM_VSIZE    "size"
#define JSON_ITEM_VQUALITY "quality"

char *vformat_list[] = {
    "H.264",
    "H.265",
};
char *vsize_list[] = {
    "720P",
    "1080P",
};
char *vquality_list[] = {
    "low",
    "mid",
    "high",
};

typedef struct {
    pthread_t pid;
    // int stack_size;
    // char name[16];
    char running;
    char exit;
} pthread_manger_t;

static pthread_manger_t sg_pth_lvgl = {0};

static lv_color_t sg_lcd_buf1[LCD_SCREEN_WIDTH * LCD_SCREEN_HEIGHT / 2];
static lv_color_t sg_lcd_buf2[LCD_SCREEN_WIDTH * LCD_SCREEN_HEIGHT / 2];

int i2c_fd2 = 0;
int lcd_fd = 0;
I2CDevice dev_ft6206;
I2CDevice dev_mpu6050;
gyro_log_init_param gyro_cfg;

static uint32_t process_exit = 0;
void main_exit(int sig)
{
    printf("vIpcExit by signal:%d\n", sig);
    process_exit = 1;
}

static void set_hi_reg(void)
{
    // I2C0 设置
    // I2C0_SCL I2C0_SDA 设置为 I2C
    himm(0x112c0030, 0x00001c01);
    himm(0x112c0034, 0x00001c01);
    // LCD_DATA6 LCD_DATA7 设置为 GPIO
    himm(0x112c0060, 0x00001170);
    himm(0x112c0064, 0x00001170);

    // I2C2 设置
    // I2C2_SCL I2C2_SDA 设置为 GPIO
    himm(0x112c0038, 0x00001c00);
    himm(0x112c003c, 0x00001c00);
    // LCD_DATA4 LCD_DATA5 设置为 I2C2
    himm(0x112c0058, 0x00001172);
    himm(0x112c005c, 0x00001172);


    // SPI0 设置
    // SPI0_SCLK
    himm(0x112C003C, 0x00001c00);
    himm(0x112C0074, 0x00001177);
    // SPI0_SDO
    himm(0x112C0038, 0x00001c00);
    himm(0x112C006C, 0x00001137);
    // SPI0_SDI
    himm(0x112C0070, 0x00001137);
    // SPI0_CSN
    himm(0x112C0040, 0x00001000);
    himm(0x112C0068, 0x00001137);


    // GPIO 设置
    himm(0x100C0008, 0x00001D30); // GPIO
    // himm(0x100C0008, 0x00001D31); // UPDATE_MODE


    // PWM 设置
    // TODO


    // ADC 引脚复用设置
    himm(0x120C0000, 0x00000001); // ch0
    // himm(0x120C0004, 0x00000001); // ch1


    // 音视频等相关设置
    // 时钟引脚
    himm(0x112c0028, 0x00001001);
    himm(0x112c0054, 0x00001A00);
    // 开启24MHz时钟
    himm(0x120100f0, 0x0000000D);

    // MIPI 接口设置
    // MIPI_RX_CK0N
    himm(0x112c000, 0x00001000);
    // MIPI_RX_CK0P
    himm(0x112c004, 0x00001000);
    // MIPI_RX_D0N
    himm(0x112c008, 0x00001000);
    // MIPI_RX_D0P
    himm(0x112c00c, 0x00001000);
    // MIPI_RX_D2N
    himm(0x112c010, 0x00001000);
    // MIPI_RX_D2P
    himm(0x112c014, 0x00001000);

    return;
}

float get_cpu_temp(void)
{
#ifdef ENABLE_SIMULATE_SYSTEM_CALL
    return 56.78
#else
    float temp = 0.0;
    uint32_t reg = 0;
    reg = himd(0x120280BC);
    reg = reg & 0x00000FFF;
    temp = ((reg-117)/798.0)*165-40;
    return temp;
#endif
}

float get_battery_voltage(void)
{
#ifdef ENABLE_SIMULATE_SYSTEM_CALL
    static float voltage = 4.20;
    voltage -= 0.05;
    if (voltage < 3.3) {
        voltage = 4.20;
    }
    return voltage;
#else
    uint32_t adc = 0;
    float voltage = 0.0;
    adc = hiadc_get_ch0();
    voltage = 3.3 / (10.0 / (10.0 + 4.7)) * (float)adc / 1024.0;
    return voltage;
#endif
}

int save_json_cfg(video_format_e format, video_size_e size, video_quality_e quality)
{
    char json_buf[1024];
    cJSON *root_obj;

    memset(json_buf, 0, sizeof(json_buf));

    root_obj = cJSON_CreateObject();
    cJSON_AddStringToObject(root_obj, JSON_ITEM_VFORMAT, vformat_list[format]);
    cJSON_AddStringToObject(root_obj, JSON_ITEM_VSIZE, vsize_list[size]);
    cJSON_AddStringToObject(root_obj, JSON_ITEM_VQUALITY, vquality_list[quality]);
    cJSON_PrintPreallocated(root_obj, json_buf, sizeof(json_buf), 1);
    cJSON_Delete(root_obj);

    FILE *fp = fopen(JSON_CONFIG_FILE_NAME, "w");
    fwrite(json_buf, 1, strlen(json_buf), fp);
    fclose(fp);

    return 0;
}

int read_json_cfg(video_format_e *format, video_size_e *size, video_quality_e *quality)
{
    char json_buf[1024];
    cJSON *root_obj;
    cJSON *tmp_obj;
    char *val;
    int i;

    memset(json_buf, 0, sizeof(json_buf));

    if (access(JSON_CONFIG_FILE_NAME, F_OK) != 0) {
        // 创建默认设置
        *format = VIDEO_FORMAT_H264;
        *size = VIDEO_SIZE_1920_1080;
        *quality = VIDEO_QUALITY_MID;
        save_json_cfg(*format, *size, *quality);
        return 0;
    }

    FILE *fp = fopen(JSON_CONFIG_FILE_NAME, "r");
    fread(json_buf, 1, sizeof(json_buf), fp);
    fclose(fp);

    root_obj = cJSON_Parse(json_buf);
    tmp_obj = cJSON_GetObjectItem(root_obj, JSON_ITEM_VFORMAT);
    val = cJSON_GetStringValue(tmp_obj);
    for (i = 0; i < sizeof(vformat_list)/sizeof(char *); i++) {
        if (strcmp(vformat_list[i], val) == 0) {
            *format = i;
            break;
        }
    }
    tmp_obj = cJSON_GetObjectItem(root_obj, JSON_ITEM_VSIZE);
    val = cJSON_GetStringValue(tmp_obj);
    for (i = 0; i < sizeof(vsize_list)/sizeof(char *); i++) {
        if (strcmp(vsize_list[i], val) == 0) {
            *size = i;
            break;
        }
    }
    tmp_obj = cJSON_GetObjectItem(root_obj, JSON_ITEM_VQUALITY);
    val = cJSON_GetStringValue(tmp_obj);
    for (i = 0; i < sizeof(vquality_list)/sizeof(char *); i++) {
        if (strcmp(vquality_list[i], val) == 0) {
            *quality = i;
            break;
        }
    }
    cJSON_Delete(root_obj);

    return 0;
}

int get_video_format(video_format_e *format, video_size_e *size, video_quality_e *quality)
{
    read_json_cfg(format, size, quality);
    return 0;
}

int set_hisi_video_cfg(video_format_e format, video_size_e size, video_quality_e quality)
{
    if (format == VIDEO_FORMAT_H264) {
        g_enPayLoad[0] = PT_H264;
    }
    else if (format == VIDEO_FORMAT_H265) {
        g_enPayLoad[0] = PT_H265;
    }

    if (size == VIDEO_SIZE_1280_720) {
        g_vpssSize[3] = PIC_720P;
        g_vencSize[0] = PIC_720P;
    }
    else if (size == VIDEO_SIZE_1920_1080) {
        g_vpssSize[3] = PIC_1080P;
        g_vencSize[0] = PIC_1080P;
    }

    g_br_index = quality;

    return 0;
}

int set_video_format(video_format_e format, video_size_e size, video_quality_e quality)
{
    save_json_cfg(format, size, quality);
    hisi_media_exit();
    set_hisi_video_cfg(format, size, quality);
    hisi_media_init();
    return 0;
}

void rec_key_job()
{
    static int32_t count = 0;
    static int32_t triggered = 0; // 标记按键长按是否已经触发
    key_data key_dat;
    rec_state_e rec_state = REC_STATE_IDLE;
    char path[64];
    char name[64];

    key_scan();

    key_dat = key_read();
    if (KEY_IS_FALLING(key_dat, 1)) {
        count += 1;
    }
    else if (KEY_IS_RISING(key_dat, 1)) {
        // DO NOTHING
    }
    else if (KEY_IS_PUSH(key_dat, 1)) {
        count += 1;
        // printf("key push count %d\n", count);
    }
    else {
        count = 0;
        triggered = 0;
    }

    // count 计数识别长按和短按
    if (count > 20 && triggered == 0) {
        triggered = 1;

        // 处理逻辑
        rec_state = rec_get_state();
        if (rec_state == REC_STATE_IDLE || rec_state == REC_STATE_STOP_OK) {
            memset(path, 0, sizeof(path));
            memset(name, 0, sizeof(name));

            strcpy(path, FULL_REC_PATH);
            // strcpy(name, "video"); // 简单粗暴的方案，直接使用"video+序号"，适合调试
            // 优雅一点的方案，使用系统时间
            struct tm *tm_ptr;
            time_t time_now;
            time(&time_now);
            tm_ptr = localtime(&time_now);
            strftime(name, sizeof(name), "%y%m%d_%H%M%S", tm_ptr);
            if (make_file_name(path, sizeof(path), name, sizeof(name))) {
                printf("generate filename error\n");
                return;
            }
            save_pv_img(name, pv_img_buf, sizeof(pv_img_buf));
            rec_set_filename(name); // 设置录像文件名，不含后缀名
            rec_set_state(REC_STATE_DO_START);
            gyro_log_start(name); // 设置gyroflow文件名，不含后缀名
            disable_gui_btn();
            set_rec_icon_start();
            printf("record start(%s)\n", name);
        }
        else if (rec_state == REC_STATE_START_OK) {
            rec_set_state(REC_STATE_DO_STOP);
            gyro_log_stop();
            enable_gui_btn();
            refresh_rec_time(0);
            set_rec_icon_stop();
            printf("record stop\n");
        }
    }
}

void rec_gui_job()
{
    struct timeval time_now;
    uint64_t time_now_ms;
    uint64_t time_delta_ms;
    rec_state_e rec_state = REC_STATE_IDLE;

    rec_state = rec_get_state();
    if (rec_state == REC_STATE_START_OK) {
        gettimeofday(&time_now, NULL);
        time_now_ms = time_now.tv_sec * 1000 + time_now.tv_usec / 1000;
        time_delta_ms = time_now_ms - rec_get_start_time_ms();
        refresh_rec_time(time_delta_ms);
    }
}

void my_disp_flush(lv_disp_drv_t * disp, const lv_area_t * area, lv_color_t * color_p)
{
    // printf("disp area %d %d %d %d \n", area->x1, area->x2, area->y1, area->y2);
    ssp_st7789 lcd_data;
    lcd_data.area.x1 = area->x1;
    lcd_data.area.x2 = area->x2;
    lcd_data.area.y1 = area->y1;
    lcd_data.area.y2 = area->y2;
    lcd_data.area.len = (area->x2 - area->x1 + 1) * (area->y2 - area->y1 + 1) * sizeof(lv_color_t);
    lcd_data.area.data = (uint8_t *)color_p;
    ioctl(lcd_fd, SSP_LCD_SET_DRAW_AREA, (unsigned long)&lcd_data);

    lv_disp_flush_ready(disp);         /* Indicate you are ready with the flushing*/
}

void my_button_read(lv_indev_drv_t * drv, lv_indev_data_t *data)
{
    // 物理按键独立处理，不使用lvgl处理
}

// 不同批次的触摸屏坐标系方向、都有可能不同，需要在这里自行做修正
// 有可能翻转x、翻转y、翻转xy，触摸坐标范围可能为0-99、0-128、0-200、0-240等
// 以我目前使用的触摸屏为例，它的触摸坐标系和显示屏完全相反，需要做xy翻转
// 触摸范围为 0-127，去掉屏幕四周的黑边，这里取12-116映射到0-239
#define TOUCH_FLIP_X 1
#define TOUCH_FLIP_Y 1
#define TOUCH_MIN_COOR (0)
#define TOUCH_MAX_COOR (127)
#define TOUCH_CUT_SIZE (12)
#define TOUCH_VALID_SIZE (TOUCH_MAX_COOR - TOUCH_MIN_COOR - TOUCH_CUT_SIZE * 2)

void my_mouse_read(lv_indev_drv_t *indev_drv, lv_indev_data_t *data)
{
    // 临时禁用触摸屏
    // data->state = LV_INDEV_STATE_RELEASED;
    // return;


    (void) indev_drv; /*Unused*/

    int fix_x, fix_y;
    ft6206_touch_info touch_info;
    memset(&touch_info, 0, sizeof(touch_info));
    ft6206_read((void *)&dev_ft6206, &touch_info);
    if (touch_info.num > 0) {
        // printf("num %d, pos0 %d %d, pos1 %d %d \n", touch_info.num,
        //         touch_info.points[0].x, touch_info.points[0].y,
        //         touch_info.points[1].x, touch_info.points[1].y);

        if (touch_info.points[0].event == FT6206_EVENT_PRESS_DOWN ||
            touch_info.points[0].event == FT6206_EVENT_CONTACT ) {
            data->state = LV_INDEV_STATE_PRESSED;
        }
        else if (touch_info.points[0].event == FT6206_EVENT_LIFT_UP) {
            data->state = LV_INDEV_STATE_RELEASED;
        }
        else {
            data->state = LV_INDEV_STATE_RELEASED;
        }

#if TOUCH_FLIP_X == 1
        fix_x = TOUCH_MAX_COOR - touch_info.points[0].x + TOUCH_MIN_COOR;
#else
        fix_x = touch_info.points[0].x;
#endif

#if TOUCH_FLIP_Y == 1
        fix_y = TOUCH_MAX_COOR - touch_info.points[0].y + TOUCH_MIN_COOR;
#else
        fix_y = touch_info.points[0].y;
#endif

        fix_x = fix_x - TOUCH_CUT_SIZE;
        fix_x = fix_x > TOUCH_VALID_SIZE ? TOUCH_VALID_SIZE : fix_x;
        fix_x = fix_x * LCD_SCREEN_WIDTH / TOUCH_VALID_SIZE;

        fix_y = fix_y - TOUCH_CUT_SIZE;
        fix_y = fix_y > TOUCH_VALID_SIZE ? TOUCH_VALID_SIZE : fix_y;
        fix_y = fix_y * LCD_SCREEN_HEIGHT / TOUCH_VALID_SIZE;

        data->point.x = fix_x;
        data->point.y = fix_y;
    }
}

// LVGL的接口不是线程安全的，如需多线程操作必须加锁
// 我采用无锁方案，因此所有调用LVGL接口的操作只放在这个线程中进行
void *pth_lvgl_func(void *args)
{
    uint64_t period_ms;
    struct timespec tp = {0};
    struct timespec tp_old = {0};
    int32_t ret = 0;
    uint32_t loop_count = 0;

    pthread_manger_t *pth_ctx = (pthread_manger_t *)args;
    prctl(PR_SET_NAME, "pth_lvgl");
    pth_ctx->running = 1;
    pth_ctx->exit = 0;

    // lvgl初始化
    lv_init();

    // 显存初始化
    static lv_disp_draw_buf_t lvgl_disp_buf;
    memset(sg_lcd_buf1, 0, sizeof(sg_lcd_buf1));
    memset(sg_lcd_buf2, 0, sizeof(sg_lcd_buf2));
    lv_disp_draw_buf_init(&lvgl_disp_buf, sg_lcd_buf1, sg_lcd_buf2, LCD_SCREEN_WIDTH * LCD_SCREEN_HEIGHT / 2);

    // 显示设备初始化
    static lv_disp_drv_t disp_drv;
    lv_disp_drv_init(&disp_drv);
    disp_drv.draw_buf = &lvgl_disp_buf;
    disp_drv.flush_cb = my_disp_flush;
    disp_drv.hor_res = LCD_SCREEN_WIDTH;
    disp_drv.ver_res = LCD_SCREEN_HEIGHT;
    disp_drv.antialiasing = 1;
    lv_disp_t *disp = lv_disp_drv_register(&disp_drv);

    // 物理按键初始化
    // static lv_indev_drv_t indev_drv_1;
    // lv_indev_drv_init(&indev_drv_1);
    // indev_drv_1.type = LV_INDEV_TYPE_BUTTON;
    // indev_drv_1.read_cb = my_button_read;
    // lv_indev_t *bt_indev = lv_indev_drv_register(&indev_drv_1);
    // lv_point_t button_points[1] = {{0,0}};
    // lv_indev_set_button_points(bt_indev, button_points);

    // 触摸屏初始化
    static lv_indev_drv_t indev_drv_2;
    lv_indev_drv_init(&indev_drv_2);
    indev_drv_2.type = LV_INDEV_TYPE_POINTER;
    indev_drv_2.read_cb = my_mouse_read;
    lv_indev_t *mouse_indev = lv_indev_drv_register(&indev_drv_2);

    cam_gui_init_param param;
    param.get_battery_voltage = get_battery_voltage;
    param.get_cpu_temp = get_cpu_temp;
    param.get_video_format = get_video_format;
    param.set_video_format = set_video_format;
    cam_gui_init(&param);

    if (access(DEV_DISK_NAME, F_OK) == 0) {
        set_sd_card_icon(SD_CARD_OK);
    }
    else {
        set_sd_card_icon(SD_CARD_NOT_DETECT);
    }
    set_rec_icon_stop();

    clock_gettime(CLOCK_MONOTONIC, &tp);
    tp_old = tp;

    while (!pth_ctx->exit) {
        loop_count += 1;

        // 获取缩略图，可以适当降低缩略图刷新率
        if (loop_count % 2 == 0) {
            ret = get_preview_img(pv_img_buf);
            if (ret == 0) {
                //刷新缩略图
                lv_obj_invalidate(video_preview_obj);
            }
        }

        clock_gettime(CLOCK_MONOTONIC, &tp);
        period_ms = (tp.tv_sec * 1000 + tp.tv_nsec / 1000000) - (tp_old.tv_sec * 1000 + tp_old.tv_nsec / 1000000);
        tp_old = tp;
        lv_tick_inc((uint32_t)period_ms);
        lv_timer_handler();

        rec_key_job();
        rec_gui_job();
        other_gui_job();

        usleep(25 * 1000);
    }

    lv_deinit();

    pth_ctx->running = 0;
    return NULL;
}


int main()
{
    char cmd[128] = {0};
    pthread_attr_t attr;
    time_t time_now;
    struct timeval tv;
    video_format_e format;
	video_size_e size;
	video_quality_e quality;

    process_exit = 0;
    signal(SIGTERM, main_exit);
    signal(SIGINT, main_exit);

    // 对于初次上电的的情况，设置系统默认时间，2022-01-01 00:00:00
    time(&time_now);
    if (time_now < 1640995200) {
        tv.tv_sec = 1640995200;
        tv.tv_usec = 0;
        settimeofday(&tv, NULL);
        system("hwclock -w");
    }

    // 挂载SD卡
    if (access(DEV_DISK_NAME, F_OK) == 0) {
        // 避免重复挂载
        if (read_df_cmd()) {
            sprintf(cmd, "mkdir -p %s", MOUNT_NODE);
            system(cmd);
            sprintf(cmd, "mount -t vfat %s %s", DEV_DISK_NAME, MOUNT_NODE);
            system(cmd);
            // sprintf(cmd, "mkdir -p %s", FULL_REC_PATH);
            sprintf(cmd, "mkdir -p /tmp/sd/video");
            system(cmd);
        }
    }

    // 读取配置文件
    read_json_cfg(&format, &size, &quality);
    // 设置媒体相关
    set_hisi_video_cfg(format, size, quality);

    memopen();
    set_hi_reg();
    usleep(100 * 1000);

    key_init();

    hiadc_init();
    hiadc_enable_ch0(1);

    i2c_fd2 = i2c_open("/dev/i2c-2");
    if (i2c_fd2 < 0) {
        printf("open /dev/i2c-2 error");
        return -1;
    }

    dev_ft6206.bus = i2c_fd2;
    dev_ft6206.addr = FT6202_I2C_ADDR;
    dev_ft6206.tenbit = 0;
    dev_ft6206.delay = 1;
    dev_ft6206.flags = 0;
    dev_ft6206.page_bytes = 256;
    dev_ft6206.iaddr_bytes = 1;
    ft6206_init((void *)&dev_ft6206);


    dev_mpu6050.bus = i2c_fd2;
    dev_mpu6050.addr = MPU6050_DEV_ADDR;
    dev_mpu6050.tenbit = 0;
    dev_mpu6050.delay = 1;
    dev_mpu6050.flags = 0;
    dev_mpu6050.page_bytes = 256;
    dev_mpu6050.iaddr_bytes = 1;
    // mpu6050_init((void *)&dev_mpu6050);

    gyro_log_init_param gyro_cfg;
    gyro_cfg.use_accelerometer = 1;
    gyro_cfg.use_gyroscope     = 1;
    gyro_cfg.use_magnetometer  = 0;
    gyro_cfg.reserve           = 0;
    gyro_cfg.freq              = 200;
    gyro_cfg.ascale            = 0.00012207031f; // ascale = 4/2^15 = 0.00012207031
    gyro_cfg.gscale            = 0.00053263221f; // gscale = (1000 * pi / 180)/2^15 = 0.00053263221
    gyro_cfg.mscale            = 0.0f;
    gyro_cfg.log_path          = FULL_REC_PATH;
    gyro_cfg.user_args         = (void *)&dev_mpu6050;
    gyro_cfg.sensor_name       = "mpu6050";
    gyro_cfg.sensor_init       = mpu6050_init;
    gyro_cfg.sensor_read       = mpu6050_read;
    gyro_cfg.sensor_destroy    = mpu6050_destroy;
    gyro_log_init(&gyro_cfg);

    cam_media_init(FULL_REC_PATH);
    
    if ((lcd_fd = open("/dev/st7789_lcd", O_RDWR)) == -1) {
        printf("open lcd failed\n");
        return -1;
    }
    ioctl(lcd_fd, SSP_LCD_SET_BACKLIGHT_ON, NULL);

    pthread_attr_init(&attr);
    pthread_attr_setstacksize(&attr, 256 * 1024);
    pthread_create(&sg_pth_lvgl.pid, &attr, &pth_lvgl_func, &sg_pth_lvgl);
    pthread_attr_destroy(&attr);

    // 海思媒体相关
    hisi_media_init();

    while (!process_exit) {
        // 主线程暂时没用，如果内存特别紧张可以将LVGL线程放在这里，可以节约出一个线程栈的内存
        sleep(1);
    }

end:
    hisi_media_exit();

    sg_pth_lvgl.exit = 1;
    while(sg_pth_lvgl.running) {usleep(10 * 1000);}

    cam_media_exit();

    ioctl(lcd_fd, SSP_LCD_SET_BACKLIGHT_OFF, NULL);
    close(lcd_fd);

    gyro_log_destroy();

    i2c_close(i2c_fd2);

    hiadc_deinit();

    key_exit();

    memclose();

    return 0;
}

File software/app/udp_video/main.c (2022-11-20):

#include <signal.h>

#include <stdint.h>
#include <stdio.h>
#include <stdlib.h>
#include <string.h>
#include <pthread.h>
#include <sys/time.h>
#include <sys/select.h>
#include <time.h>
#include <unistd.h>

#include "socket_udp.h"
#include "himm.h"
#include "himpp.h"
#include "camera_config.h"
#include "media_buf.h"
#include "audio_aac_adp.h"

// 目前只能测一个，不能同时启用
#define DEBUG_AUDIO 0
#define DEBUG_VIDEO 1


extern void OV5640_init(VI_PIPE ViPipe);


// UDP 相关配置
#define DEF_IP_ADDR "192.168.1.106"
int32_t cfg_port = 34543;
char *cfg_ip_addr = DEF_IP_ADDR;

uintptr_t g_udp_fd;



#define MAX_VIDEO_FRAME_SIZE (1024 * 512)

typedef struct _vframe_data_s {
    uint32_t is_i_frame;
    uint32_t frame_size;
    uint32_t frame_id; // 帧序号
    uint64_t pts_ms;
    uint8_t frame_data[1];
} vframe_data_s;

mbuf_handle *g_vframe_buf;



static uint32_t process_exit = 0;
void main_exit(int sig)
{
    printf("vIpcExit by signal:%d\n", sig);
    process_exit = 1;
}

static void set_hi_reg(void)
{
    // I2C0 设置
    // I2C0_SCL I2C0_SDA 设置为 I2C
    himm(0x112c0030, 0x00001c01);
    himm(0x112c0034, 0x00001c01);
    // LCD_DATA6 LCD_DATA7 设置为 GPIO
    himm(0x112c0060, 0x00001170);
    himm(0x112c0064, 0x00001170);

    // I2C2 设置
    // I2C2_SCL I2C2_SDA 设置为 GPIO
    himm(0x112c0038, 0x00001c00);
    himm(0x112c003c, 0x00001c00);
    // LCD_DATA4 LCD_DATA5 设置为 I2C2
    himm(0x112c0058, 0x00001172);
    himm(0x112c005c, 0x00001172);


    // SPI0 设置
    // SPI0_SCLK
    himm(0x112C003C, 0x00001c00);
    himm(0x112C0074, 0x00001177);
    // SPI0_SDO
    himm(0x112C0038, 0x00001c00);
    himm(0x112C006C, 0x00001137);
    // SPI0_SDI
    himm(0x112C0070, 0x00001137);
    // SPI0_CSN
    himm(0x112C0040, 0x00001000);
    himm(0x112C0068, 0x00001137);


    // GPIO 设置
    himm(0x100C0008, 0x00001D30); // GPIO
    // himm(0x100C0008, 0x00001D31); // UPDATE_MODE


    // PWM 设置
	// TODO


    // ADC 设置
	// TODO


    // 音视频等相关设置
    // 时钟引脚
    himm(0x112c0028, 0x00001001);
    himm(0x112c0054, 0x00001A00);
    // 开启24MHz时钟
    himm(0x120100f0, 0x0000000D);

    // MIPI 接口设置
    // MIPI_RX_CK0N
    himm(0x112c000, 0x00001000);
    // MIPI_RX_CK0P
    himm(0x112c004, 0x00001000);
    // MIPI_RX_D0N
    himm(0x112c008, 0x00001000);
    // MIPI_RX_D0P
    himm(0x112c00c, 0x00001000);
    // MIPI_RX_D2N
    himm(0x112c010, 0x00001000);
    // MIPI_RX_D2P
    himm(0x112c014, 0x00001000);

    return;
}

HI_S32 HIMPP_MPP_SYS_Init()
{
    HI_S32 s32Ret;
    HI_S32 s32PoolCnt;
    HI_U64 u64BlkSize;
    VB_CONFIG_S stVbConf;
    SIZE_S picSize;

    memset(&stVbConf, 0, sizeof(VB_CONFIG_S));
	s32PoolCnt = 0;

#if 0
	// VI 输入
    s32Ret = HIMPP_SYS_GetPicSize(g_viSize, &picSize);
    if (HI_SUCCESS != s32Ret)
    {
        HIMPP_PRT("HIMPP_SYS_GetPicSize failed!\n");
        return s32Ret;
    }
    u64BlkSize = COMMON_GetPicBufferSize(picSize.u32Width, picSize.u32Height, PIXEL_FORMAT_YVU_SEMIPLANAR_422, DATA_BITWIDTH_8, COMPRESS_MODE_NONE, DEFAULT_ALIGN);
    stVbConf.astCommPool[s32PoolCnt].u64BlkSize = u64BlkSize;
    stVbConf.astCommPool[s32PoolCnt].u32BlkCnt = 3;
	s32PoolCnt += 1;


	// VPSS 输入
	s32Ret = HIMPP_SYS_GetPicSize(g_vpssSize[0], &picSize);
    if (HI_SUCCESS != s32Ret)
    {
        HIMPP_PRT("HIMPP_SYS_GetPicSize failed!\n");
        return s32Ret;
    }
    u64BlkSize = COMMON_GetPicBufferSize(picSize.u32Width, picSize.u32Height, PIXEL_FORMAT_YVU_SEMIPLANAR_422, DATA_BITWIDTH_8, COMPRESS_MODE_NONE,DEFAULT_ALIGN);
    stVbConf.astCommPool[s32PoolCnt].u64BlkSize   = u64BlkSize;
    stVbConf.astCommPool[s32PoolCnt].u32BlkCnt    = 2;
	s32PoolCnt += 1;


    // VPSS输出
	s32Ret = HIMPP_SYS_GetPicSize(g_vpssSize[3], &picSize);
    if (HI_SUCCESS != s32Ret)
    {
        HIMPP_PRT("HIMPP_SYS_GetPicSize failed!\n");
        return s32Ret;
    }
    u64BlkSize = COMMON_GetPicBufferSize(picSize.u32Width, picSize.u32Height, PIXEL_FORMAT_YVU_SEMIPLANAR_420, DATA_BITWIDTH_8, COMPRESS_MODE_NONE,DEFAULT_ALIGN);
    stVbConf.astCommPool[s32PoolCnt].u64BlkSize   = u64BlkSize;
    stVbConf.astCommPool[s32PoolCnt].u32BlkCnt    = 2;
	s32PoolCnt += 1;
#endif

    // VI VPSS 共用缓存
	s32Ret = HIMPP_SYS_GetPicSize(g_vpssSize[0], &picSize);
    if (HI_SUCCESS != s32Ret)
    {
        HIMPP_PRT("HIMPP_SYS_GetPicSize failed!\n");
        return s32Ret;
    }
    u64BlkSize = COMMON_GetPicBufferSize(picSize.u32Width, picSize.u32Height, PIXEL_FORMAT_YVU_SEMIPLANAR_420, DATA_BITWIDTH_8, COMPRESS_MODE_NONE,DEFAULT_ALIGN);
    stVbConf.astCommPool[s32PoolCnt].u64BlkSize   = u64BlkSize;
    stVbConf.astCommPool[s32PoolCnt].u32BlkCnt    = 5;
	s32PoolCnt += 1;


    stVbConf.u32MaxPoolCnt = s32PoolCnt;

    if (0 == g_u32SupplementConfig)
    {
        s32Ret = HIMPP_SYS_Init(&stVbConf);
    }
    else
    {
        s32Ret = HIMPP_SYS_InitWithVbSupplement(&stVbConf, g_u32SupplementConfig);
    }

    if (HI_SUCCESS != s32Ret)
    {
        HIMPP_PRT("HIMPP_SYS_GetPicSize failed!\n");
        return s32Ret;
    }

    return HI_SUCCESS;
}


// 用于从编码器获取数据
HI_S32 get_hisi_video_frame(VENC_CHN VencChn, VENC_STREAM_S* pstStream)
{
    int32_t frame_size = 0;
    int32_t offset = 0;
    int32_t i = 0;

    for (i = 0; i < pstStream->u32PackCount; i++)
    {
        int pack_size = pstStream->pstPack[i].u32Len - pstStream->pstPack[i].u32Offset;
        frame_size += pack_size;
    }

    if (frame_size > MAX_VIDEO_FRAME_SIZE) {
        printf("frame size is %d, larger than buffer size %d\n", frame_size, MAX_VIDEO_FRAME_SIZE);
        return HI_SUCCESS;
    }

    if (mbuf_is_full(g_vframe_buf)) {
        mbuf_free(g_vframe_buf);
    }

    vframe_data_s *vdata;
    vdata = (vframe_data_s *)mbuf_write_no_cp(g_vframe_buf, frame_size + offsetof(struct _vframe_data_s, frame_data));
    if (vdata) {
        vdata->is_i_frame = 0;
        vdata->frame_size = frame_size;
        vdata->frame_id = pstStream->u32Seq;
        vdata->pts_ms = pstStream->pstPack->u64PTS / 1000;
        for (i = 0; i < pstStream->u32PackCount; i++)
        {
            if (g_enPayLoad[i] == PT_H264) {
                if (pstStream->pstPack[i].DataType.enH264EType >= H264E_NALU_IDRSLICE) {
                    vdata->is_i_frame = 1;
                }
            }
            else if (g_enPayLoad[i] == PT_H265) {
                if (pstStream->pstPack[i].DataType.enH265EType >= H265E_NALU_IDRSLICE) {
                    vdata->is_i_frame = 1;
                }
            }

            int pack_size = pstStream->pstPack[i].u32Len - pstStream->pstPack[i].u32Offset;
            uint8_t *addr = pstStream->pstPack[i].pu8Addr + pstStream->pstPack[i].u32Offset;
#if DBG_DUMP_HISI_RAW_VIDEO_DATA
        if (VencChn == DUMP_VENC_CHN) {
            fwrite(addr, 1, pack_size, fpw);
        }
#endif
            memcpy(&vdata->frame_data[offset], addr, pack_size);
            offset += pack_size;
        }
        mbuf_write_end_no_cp(g_vframe_buf);
    }

    return HI_SUCCESS;
}
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

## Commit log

2022-07-27 feat: 新建文件夹
2022-08-12 feat: 添加海思寄存器读写接口
2022-08-14 feat: 添加I2C设备代码
2022-08-24 feat: 添加OV5640驱动
2022-11-13 doc: 添加文档
2022-11-13 feat: 添加spi接口
2022-11-13 feat: 添加gpio接口
2022-11-13 feat: 添加st7789液晶屏驱动
2022-11-13 feat: 添加触摸屏驱动程序
2022-11-13 feat: 添加外设测试程序
2022-11-13 feat: 添加lvgl_8.3.0源码
2022-11-13 feat: 添加st7789内核驱动
2022-11-13 feat: 完善外设测试程序
2022-11-13 feat: 添加遗漏的LVGL源文件
2022-11-13 feat: 添加lvgl测试程序
2022-11-13 feat: 添加libmpeg库
2022-11-13 feat: 添加UDP测试音视频流功能
2022-11-20 fix: 修复一处屏幕显示bug
2022-11-20 fix: 修复st7789驱动中清屏函数的bug
2022-11-20 feat: 屏幕显示摄像头缩略图功能开发完成
2022-11-20 feat: 添加gyroflow日志记录功能
2022-11-20 feat: 适配 stb_truetype 作为 lvgl 的字体引擎
2022-11-20 doc: 添加logo设计原稿
2022-11-20 feat: 初步完成GUI界面开发
2022-11-20 fix: 修复mpu6050量程错误
2022-11-20 feat: 添加字体文件
2022-11-20 feat: 添加物理按键相关代码
2022-11-20 feat: 添加ADC驱动，完善ADC测试代码
2022-11-20 feat: 添加cJSON库
2022-11-20 doc: 添加spi调试文档
2022-11-20 feat: 添加u-boot和kernel需要修改的代码
2022-11-20 feat: 所有功能开发完成
2022-11-20 doc: 添加硬件资料
2022-11-20 fix: 修复一些小问题
2022-11-20 doc: 添加原理图和PCB
2022-11-20 doc: 添加外壳模型
    [Action_2_Poor_3DP.f3d, Action_2_Poor_CNC_v2.f3d, shell1.step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]
2022-11-20 fix: 添加遗漏的Makefile
2022-11-21 feat: 添加固件
2022-11-23 doc: 完善文档
    [成本估算及采购渠道.xlsx]
